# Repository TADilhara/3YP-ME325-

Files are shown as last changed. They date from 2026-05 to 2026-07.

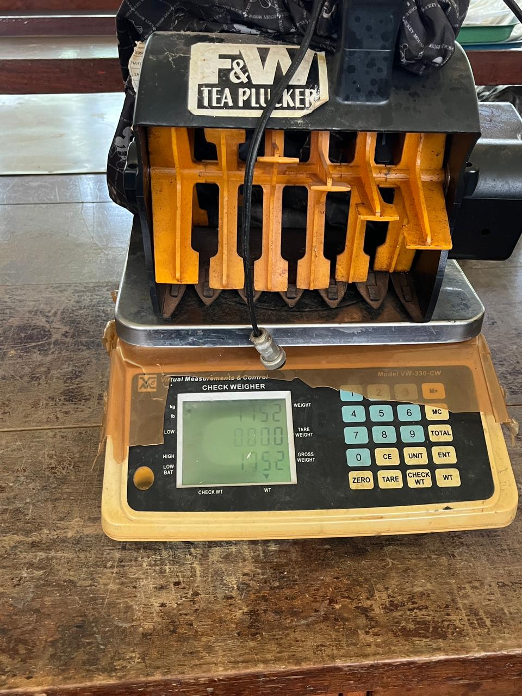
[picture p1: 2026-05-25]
Field_Observations_01/Images/IMG_9.jpeg

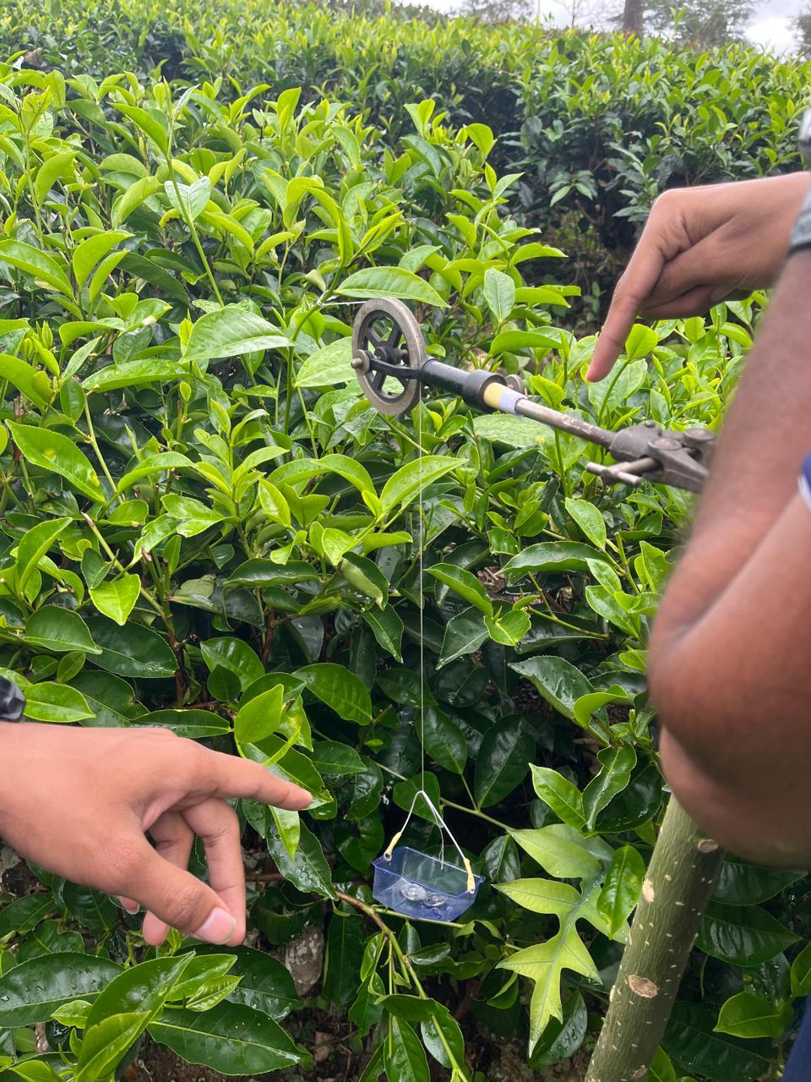
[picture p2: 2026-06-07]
Field_Observations_02/Images/IMG_8.jpeg

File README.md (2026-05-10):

Improved Tea Harvesting Machine Project

Project Overview
This repository contains the documentation, research, and design files for our 3rd-year Mechanical Engineering project. Our objective is to modify and improve existing tea plucking machinery to enable the collection of premium tea products.

Team Members
* Theekshana Dilhara (E/21/097)
* Yugan Shachithra (E/21/099)
* Keshani Kawshalya (E/21/218)

Instructors & Supervisors:
* Course Coordinator: Dr. Sanjeeva Maithripala
* Supervisor: Dr. Elan Sivakumar

Project Log & Milestones

1. Field Research & Site Visits
* Conducted a site visit to the Tea Research Institute Low country Regional Centre,Ratnapura.
* Observed current harvesting methods and identified practical field constraints.

2. Literature Review
* Analyzed existing research papers regarding tea harvesting mechanisms.
* Extracted key data to form the theoretical foundation of our modifications.

3. Conceptualization & Supervisor Meetings
* Conducted brainstorming and feedback sessions with our project supervisor.
* Developed initial mechanical concepts and design directions based on our field research and literature review.

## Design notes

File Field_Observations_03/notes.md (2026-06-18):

# Field Visit & Prototyping Notes: Meewathura Field Premises

**Date:** 10/06/2026  
**Purpose:** Field testing of the physical prototype for 'Guide A'.  
**Attendees:** 
* E/21/097 Dilhara
* E/21/099 Dilshan
* E/21/218 Kaushalya

**Academic Contacts:**  Prof. A.J. Mohotti (Department of Crop Science, Faculty of Agriculture, University of Peradeniya)

## Technical Prototyping Workflow

### 1. Prototype Fabrication
* **Material Selection:** To allow maximum visual tracking of the tea shoots as they slide through the channel, a 5 mm thick clear **Perspex (Acrylic)** sheet was selected.
* **Manufacturing Process:** Using the precise CAD layout from our design files (`Guide_A.pdf`), a 275 mm long scaled test segment of the guide channel was processed using the CNC laser cutter machine located in the Department of Manufacturing and Industrial Engineering.

### 2. Field Testing Methodology
* **Location:** Field experiments were conducted at the tea plots within the Meewathura premises under the guidance of Prof. A.J. Mohotti.
* **Mechanism Simulation:** To validate the tooth spacing, channel width, and sequence of the dual-sorting concept without building full spring sub-assemblies, the physical Perspex guide was passed over living bushes. Human fingers were utilized to manually simulate the mechanical resistive forces of the 1st and 2nd gates.

---

## Key Technical Observations & Encountered Challenges

The initial test confirmed that the basic sliding clearance and physical pathing of the guide work well. However, three critical behavioral problems were isolated during shoot interaction:

### 1. Second Gate Angular Misalignment (Harvestable Shoot Escape)
* **Observation:** The 1st gate successfully filters out the flexible *Arimbu* shoots. This leaves a dense mixture of optimal harvestable shoots and stiff over-mature stalks entering the zone of the 2nd gate.
* **The Problem:** Because the 2nd gate's angular geometry was identical to the first, optimal harvestable shoots were frequently forced to bend too heavily and slip right past the 2nd gate instead of triggering it. As a result, these high-quality leaves bypassed the cutting plane entirely and were left unharvested.

### 2. Shoot Clustering (Bunch of Tea Shoots Phenomenon)
* **Observation:** Tea shoots do not always enter the guide teeth as isolated, individual stalks; they frequently enter as a tightly packed **bunch of tea shoots**.
* **The Problem:** When a dense bunch of tea shoots strikes the gates, the combined collective force of multiple harvestable/mature shoots easily overpowers the gate pre-load simultaneously. This causes the gates to blow wide open, destroying the sorting selectivity and allowing *Arimbu* within the bunch to be cut, or mature wood to pass.

### 3. Forward Leaning Stalks & Collection Loss (Falling Defect)
* **Observation:** As shoots approach the final cutting plane near the reciprocating blades, they exhibit a distinct forward leaning profile (bending toward the front of the machine).
* **The Problem:** Immediately after the cutter bar shears the stem, the forward momentum and preset lean cause the severed shoot to flip and **fall down forward** onto the field floor instead of being swept backward into the collection bag. This introduces an unacceptable crop collection loss.

---

## Iterative Design Modifications & Solutions

To resolve these three field-identified bottlenecks, our group is shifting from a single geometry to an comparative array testing workflow:

* **Development of Guides B and C:** We are designing two additional guide variants with localized, targeted geometric adjustments:
  * **Optimized 2nd Gate Trajectory:** Altering the entry angle and length of the second channel slot to reduce the deflection requirements for harvestable leaves, ensuring they are consistently guided directly to the blade.
  * **Anti-Tumble Extension Profiles:** Modifying the front lip of the teeth to brace leaning stalks upright right up to the millisecond of the cut, preventing the forward falling defect.
  * **Cluster-Breaking Tooth Profiling:** Introducing subtle modifications to the entry nose of the teeth to mechanically break apart "Pokura" clusters into individual lines before they strike the first gate pocket.

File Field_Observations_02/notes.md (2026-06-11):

# Field Visit Notes: 	Tea Research Institute of Sri Lanka, Talawakelle

**Date:** 22/05/2026  
**Purpose:** Primary mechanical property data collection and structural analysis – measure shoot bending forces, evaluate stem diameter profiles.  
**Attendees:** 

* E/21/097 Dilhara
* E/21/099 Dilshan
* E/21/218 Kaushalya
* Dr. Elan Sivakumar (Project Supervisor / Department of Mechanical Engineering, University of Peradeniya)

## Key Observations & Data Collection

### 1. Custom Bending Force Apparatus
To determine the stiffness boundary conditions for our selective mechanism design, our team deployed a custom mechanical testing apparatus directly in the field patches.
* **Component Assembly:** The system utilizes a rigid structural clamp to secure the base of the living tea stem without crushing the plant tissue. A low-friction pulley wheel with an integrated holder is aligned horizontally with the target pluck point via a high-tensile thread link. The thread terminates at a calibrated scale pan used to apply incremental vertical loads.
* **Testing Methodology:** Force application is managed using calibrated laboratory weights supplemented by a precise combination of Sri Lankan currency coins (with known masses verified in our coin-weight lookup tables) to achieve fractional gram sensitivities. Weights are added slowly until the stalk reaches its critical large-deflection bending threshold, allowing us to back-calculate the mechanical yield limits in Newtons ($F = m \cdot g$).

### 2. Shoot Bending Force & Stem Diameter Metrics
Using our custom testing apparatus and precision vernier calipers, we successfully isolated the distinct mechanical properties separating immature, harvestable, and over-mature stalks:
* **Arimbu (Immature Stems):** Displayed a highly flexible biological nature with a narrow stem diameter. The maximum force threshold required to bend an *Arimbu* shoot tip safely sat at **0.1089 N**, setting our mechanism's absolute baseline resistance limit.
* **Harvestable Shoots (Pluckable):** Standard "2-3 leaves and a bud" structures showed a clean nominal diameter profile at their natural breaking points. These shoots displayed a clear force range starting from a minimum of **0.1178 N** up to a maximum peak of **0.3226 N**.
* **Mature Shoots (Coarse Wood Stalks):** Heavily lignified, dense mature stems exhibited significantly larger cross-sectional diameters, requiring extreme forces exceeding **0.50 N - 0.70 N** to achieve deflection, validating our stiffness-sorting criteria.

### 3. Field Agronomy & Structural Observations
* **Manual Harvesting Baseline:** Accompanied by the TRI officers, we monitored plantation pluckers to study the kinematic motion of hand selection. Experienced labor isolates pluckable shoots with high accuracy, leaving delicate *Arimbu* tips pristine for subsequent 7-day or 9-day cycles.
* **Morphological Features:** Detailed structural evaluations confirmed that the mechanical layout must adapt to variable stalk maturity across uneven tea tables, confirming that a geometry-only sorting method is insufficient compared to our stiffness-gate approach.

### 4. Commercial Tea Factory Processing Pipeline
* **Industrial Validation:** Visited the manufacturing plant facilities to analyze how mechanical harvesting affects subsequent processing stages.
* **Coarse Leaf Impact:** Factory operators confirmed that non-selective machine harvesting introduces high percentages of coarse wood stems, which disrupts the automated sifting/withering machines and degrades the overall value grade of the final product.

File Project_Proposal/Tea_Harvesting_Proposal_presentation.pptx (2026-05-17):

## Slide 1

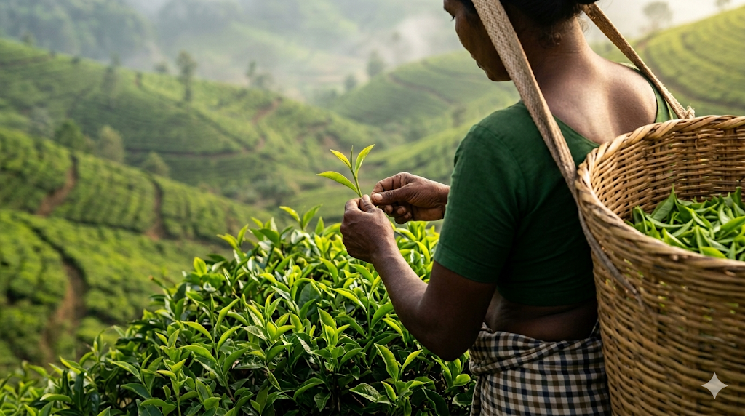
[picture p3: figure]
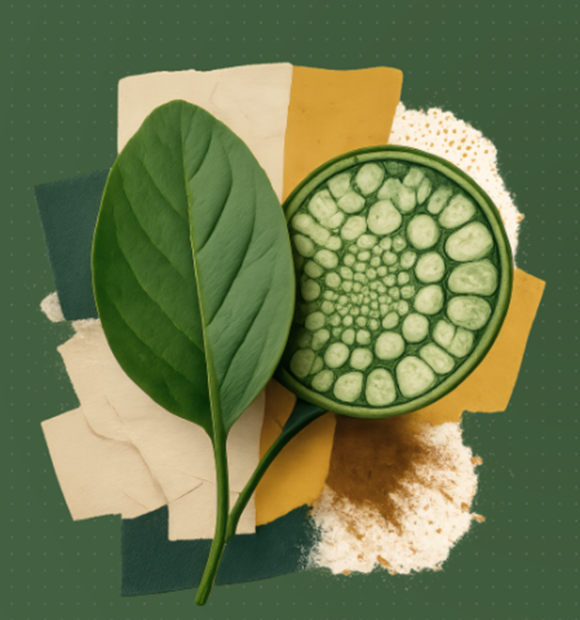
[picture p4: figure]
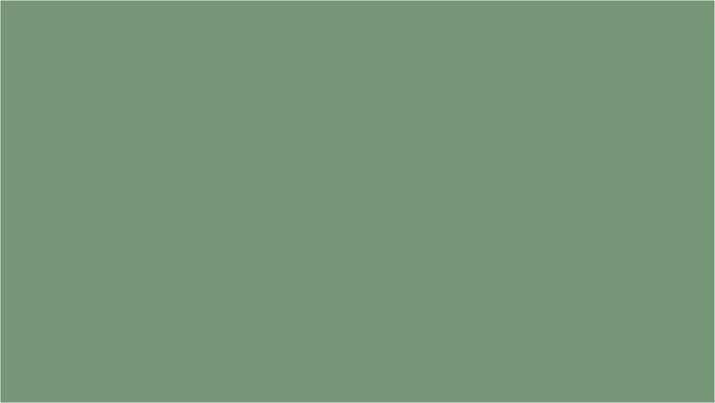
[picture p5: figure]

Adaptive Design for
Precision Tea Harvesting

Evaluation of Existing Systems &
Development of Improvement Recommendations

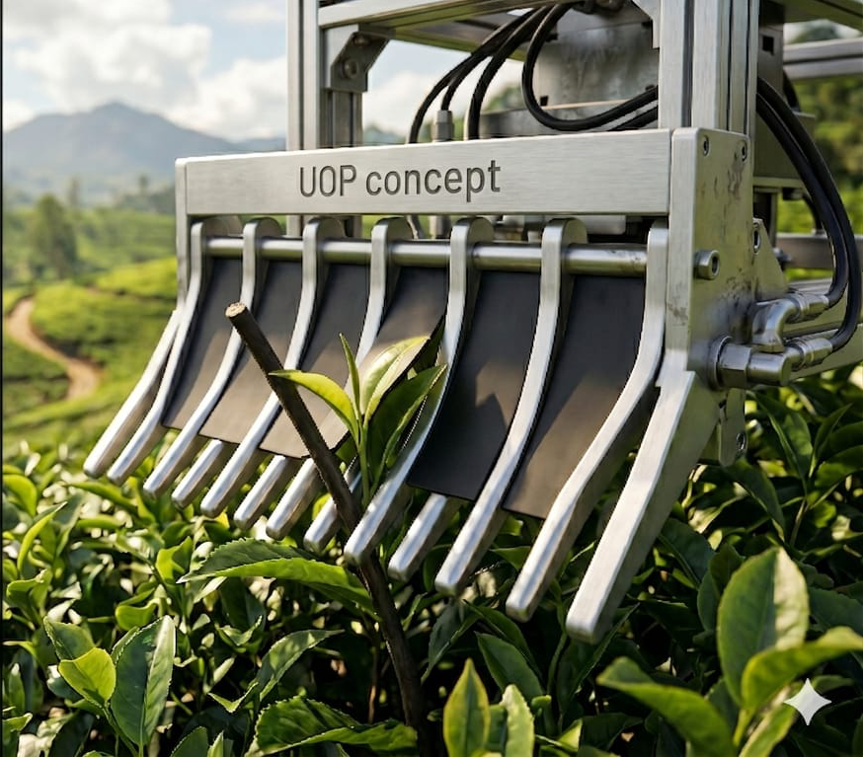
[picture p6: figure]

🍃 Tea Harvesting Research

ME325 — Mechanical Engineering Group Project

Group Members
Theekshana Dilhara [E/21/097]
Yugan Sachithra [E/21/099]
Keshani Kaushalya [E/21/218]

Supervised by
Dr. Elan Sivakumar

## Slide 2

TEA SHOOT BIOLOGY & PLUCKING SCIENCE

- Understanding tea shoot anatomy is essential to designing a selective harvesting mechanism.

01

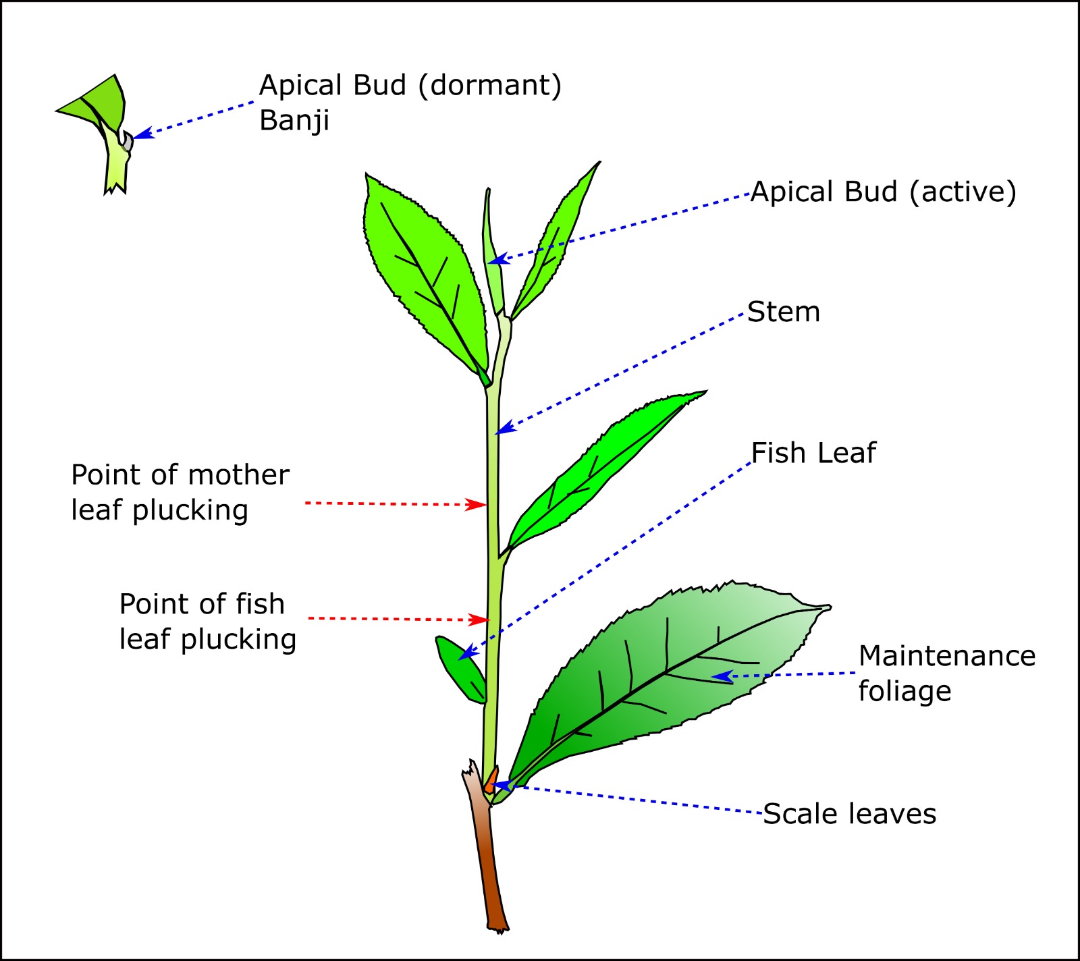
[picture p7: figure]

🌱 Shoot Growth Stages (a → e)

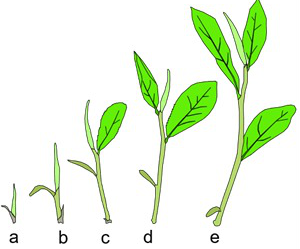
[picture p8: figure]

🍃 Key Plucking Facts

- • Pluckable shoot = Apical Bud + 2–3 tender leaves
- • Arimbu = immature shoot — must NOT be harvested
- • Banji = dormant bud — not ideal for plucking
- • Maintenance foliage must be preserved for photosynthesis
- • Fish leaf marks the lower boundary of plucking zone

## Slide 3

THE PROBLEM & AIM

02

📌 PROBLEM: Labour shortages and rising costs are forcing tea estates to adopt mechanical harvesting — but current machines damage leaves, lack selectivity, and fail on steep Sri Lankan terrain.

❌ WHY CURRENT MACHINES FAIL

- Machines cannot detect precise plucking level
- Cannot distinguish Arimbu / banji shoots
- 35–40% yield loss; heavy leaf damage

✅ PROPOSED APPROACH

Selective harvesting — targets only pluckable shoots
Evaluates stem rigidity, bending angles & node count
Computer vision and sensors to detect buds in real time
Adaptable cutting height for uneven terrain
Reduced leaf damage & improved tea quality
Data-driven design validated through FEA & simulation

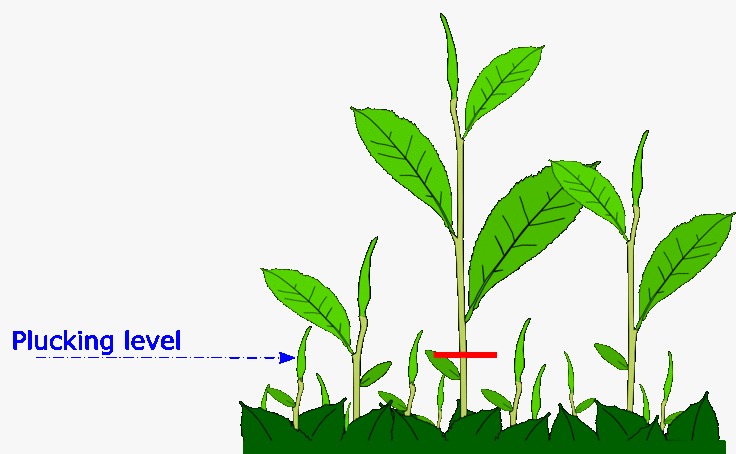
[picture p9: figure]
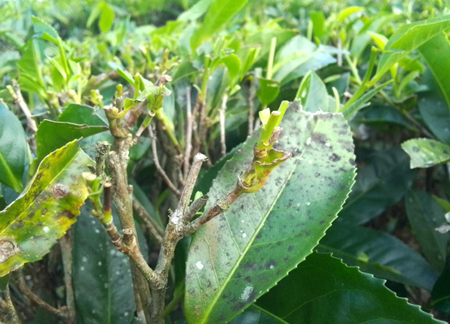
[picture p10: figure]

VS

🎯 AIM: Conduct a systematic comparative analysis of tea plucking harvesters and propose practical design improvements for Sri Lankan plantation conditions.

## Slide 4

COMPARATIVE ANALYSIS OF TEA PLUCKING MACHINES

03

- Field study informed by Tea Research Institute of Sri Lanka (TRI), Rathnapura

Criterion | Kawasaki Petrol Operated Harvester | Kawasaki Impeller | Battery Harvester | TRI Shear Plucker | Static Teeth
Power Source | Petrol | Battery ✅ | Battery ✅ | Human | Battery ✅
Daily Output | 0.7–1.0 ac/day (15× faster) | < NV60H (10× faster) | 30+ kg/hr (similar speed) | 4.3 kg/hr (2× faster) | Very low
Leaf Quality | Poor — many broken leaves | Poor — fans bruise leaves | Moderate < 10% coarse | Good — close to manual | Very poor — teeth jam
Selectivity | None | None | Low | Partial | None
Sri Lanka Terrain | Hilly (partly) | Hilly (partly) | Any land | Any land | Not tested
SL Pluck Cycle | 14–16 days ✅ | 14–16 days ✅ | 14–16 days ✅ | 7 days ✅ | Not suitable
Overall Rating | 🟢🟢🟢⚪⚪ 3 / 5 | 🟡🟡⚪⚪⚪ 2 / 5 | 🟢🟢🟢⚪⚪ 3 / 5 | 🟢🟢🟢🟢⚪ 4 / 5 | 🔴⚪⚪⚪⚪ 1 / 5

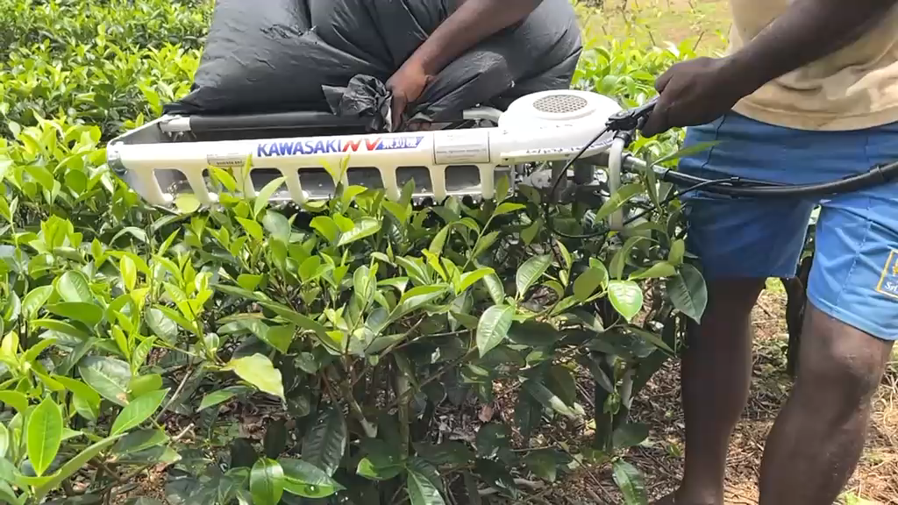
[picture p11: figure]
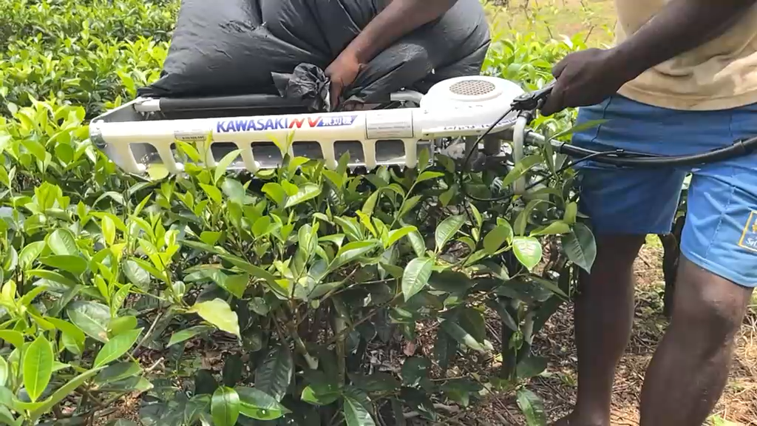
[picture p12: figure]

Operation of the currently using machine

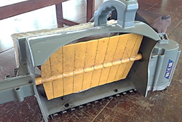
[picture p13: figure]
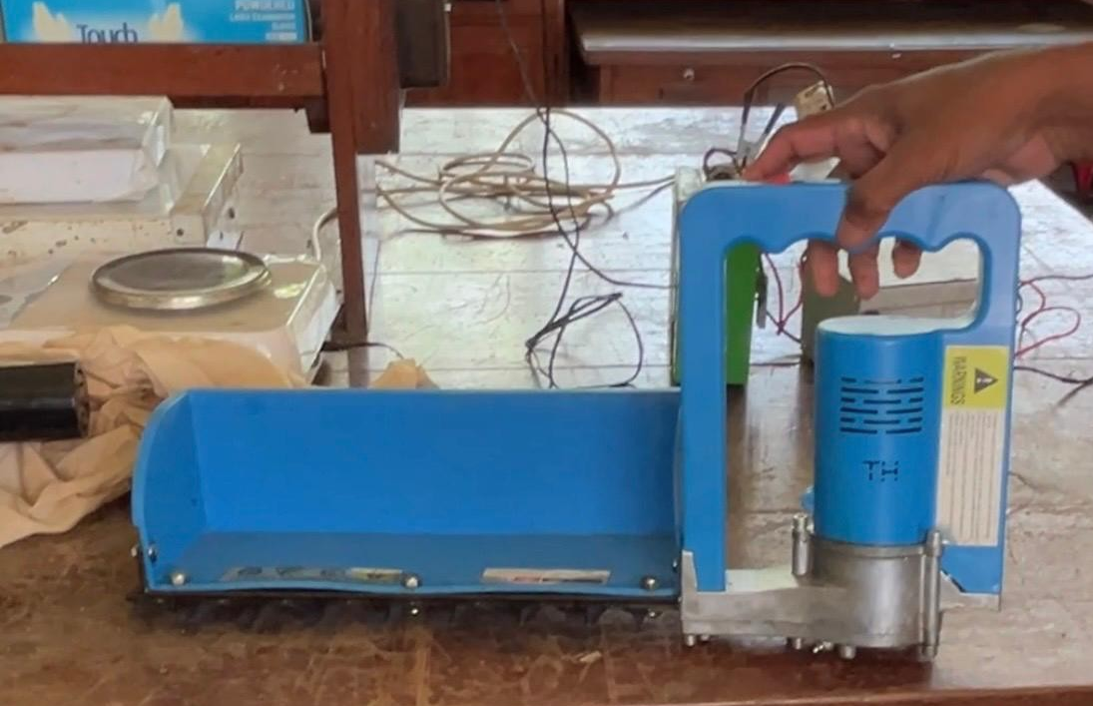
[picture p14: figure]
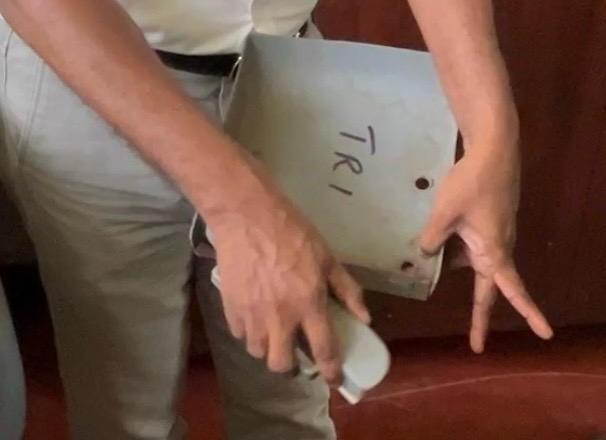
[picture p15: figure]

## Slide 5

📡 Concept A: Sensor-Guided Bending Shear

ENGINEERING DESIGN & METHODOLOGY

🤖 Concept C: Stiffness Based Selection Gate

A mechanical comb attachment uses flexible strips to sort shoots by stem stiffness. Flexible immature shoots bend safely underneath the gates, while rigid mature stems push the gates open to reach the cutting blades.

04

🔬 Concept B: Optical Micro-Shear System

Front facing camera scans canopy, identifies the topmost bud, and counts leaf nodes. If node count ≥ 3, a localized micro-shear severs the specific stem without collateral damage.

Exploits stem flexural rigidity. Deflector bends mature stems to 80° yield point. Sensor array detects bud position → dynamically adjustable blade targets the exact internode.

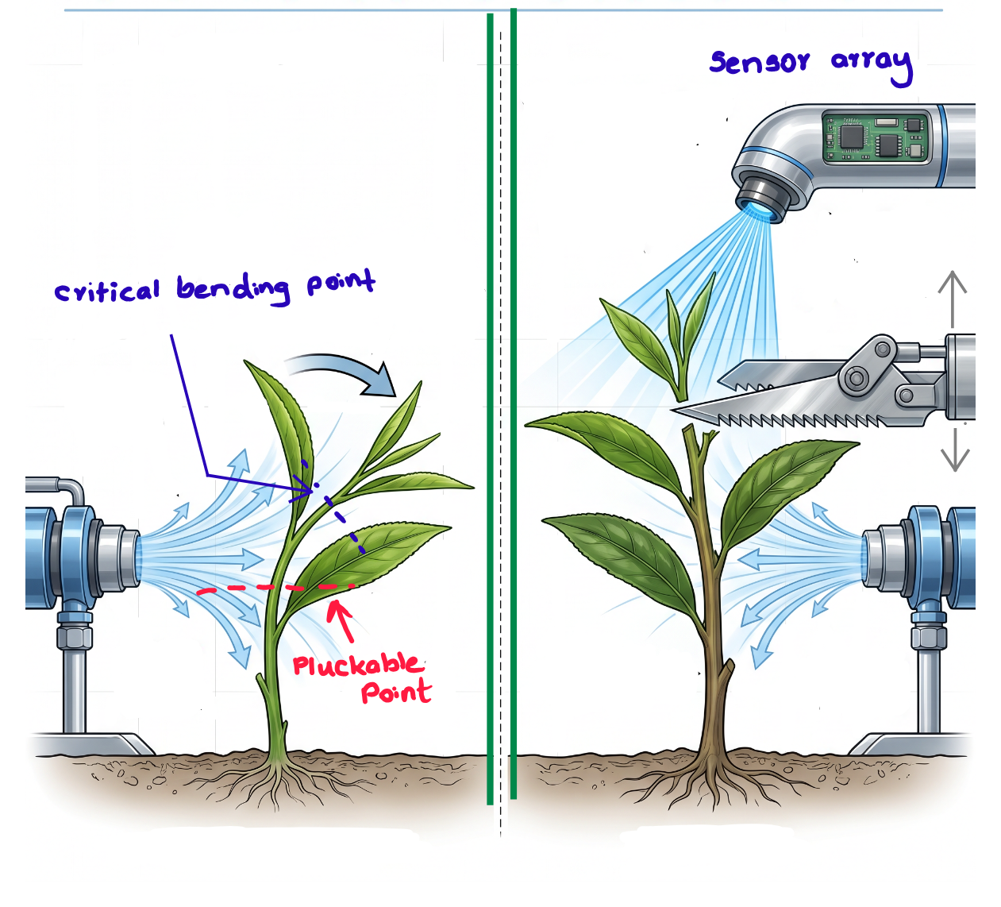
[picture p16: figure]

SOFTWARE TOOLS:

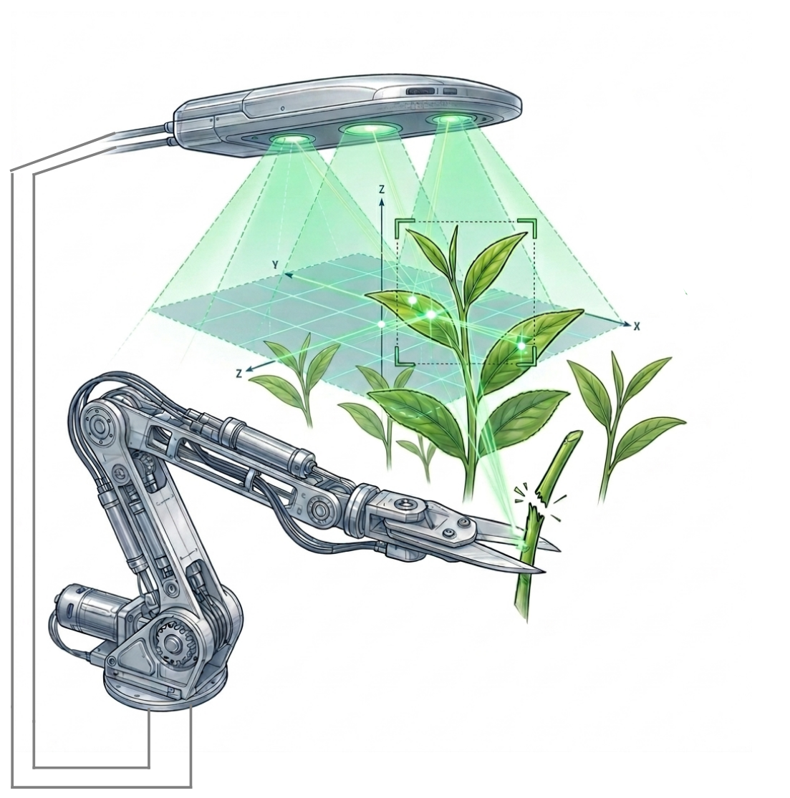
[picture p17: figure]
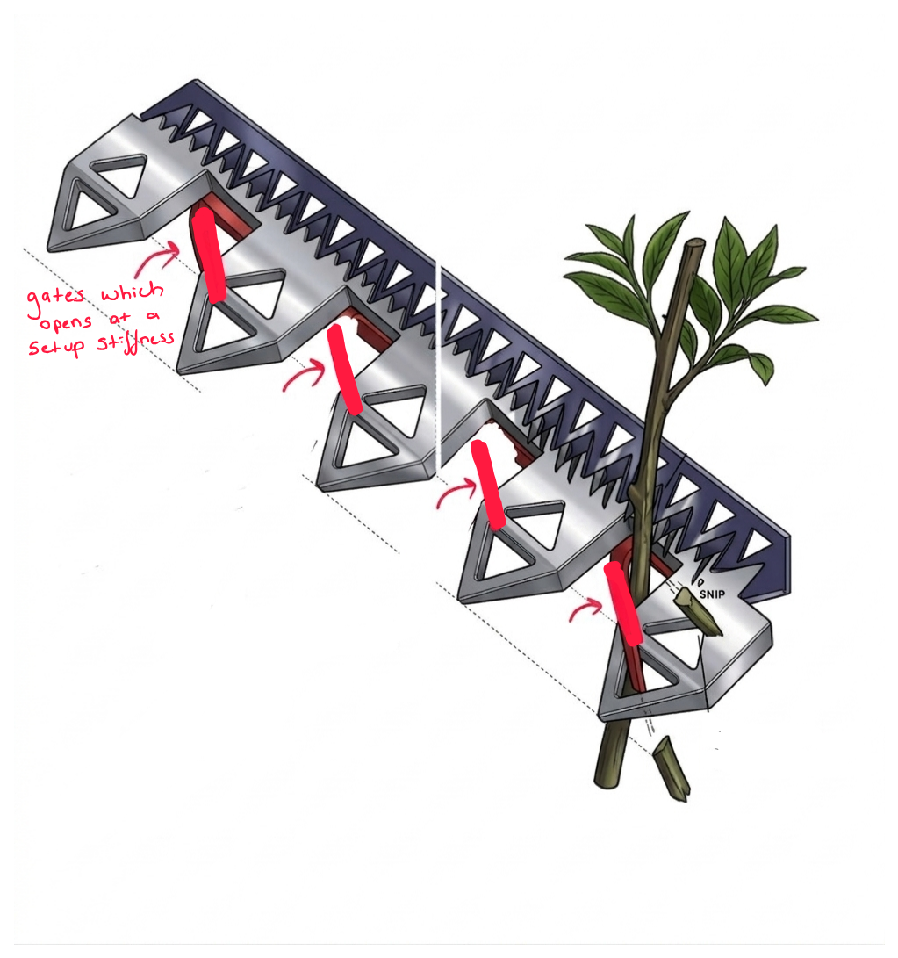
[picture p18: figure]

SolidWorks 2024 · Ansys FEA · MATLAB / Python · GitHub

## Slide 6

PROJECT TIMELINE — 4 MILESTONES

05

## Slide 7

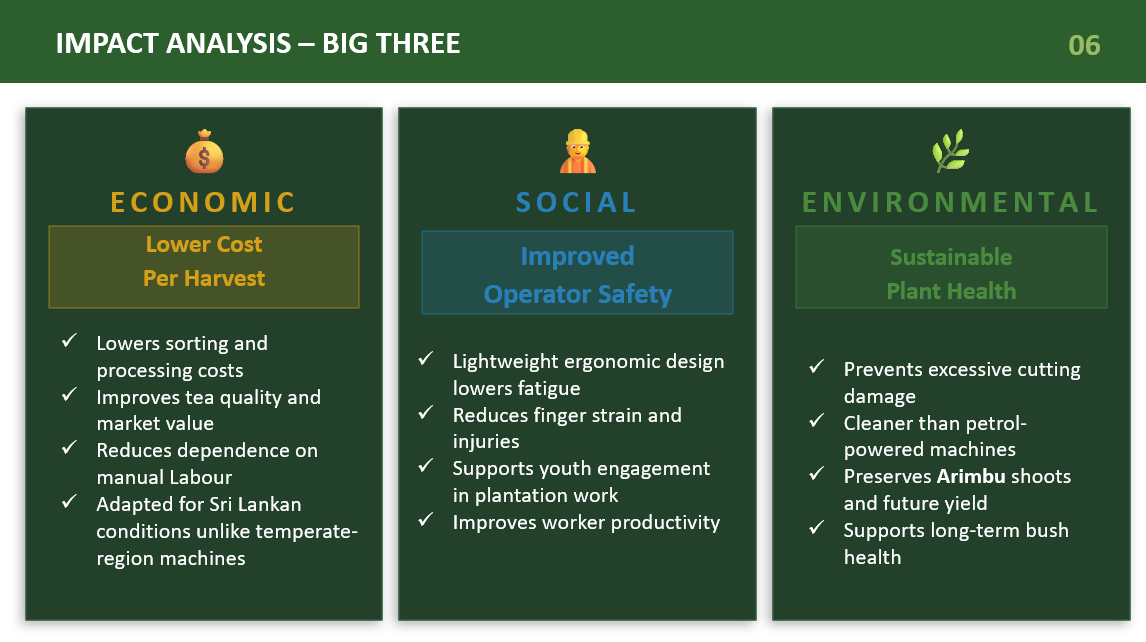
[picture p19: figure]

Ready for the Next Generation of Tea Harvesters?
Let’s innovate, Efficient & Quality-Oriented Solutions

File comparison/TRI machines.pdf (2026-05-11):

Machine | Power Source | Weight/ kg | Cutting Mechanism | Output / Efficiency | Figures

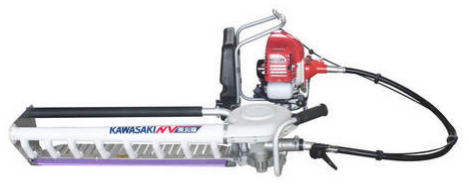
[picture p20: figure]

Kawasaki NV60H | Petrol (TU26 Mitsubishi engine, 2 Stroke, Air cool) | 9.4 (Engine 6.2kg) | Shear blades (Blade length 600mm) | 0.7–1.0 acre/day, ~15× faster than manual plucking

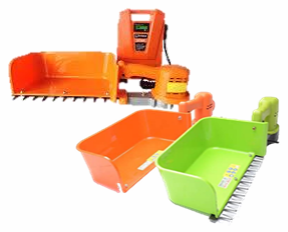
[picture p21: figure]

Single Hand Electric Tea Harveste r | Battery powered | 1.8 | Shear blades (Blade length 330mm) | 30+ kg/hr (similar speed)

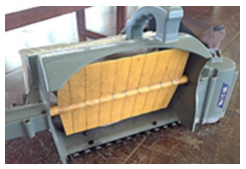
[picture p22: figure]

Kawasaki Impeller machine | Battery powered | 3.5 | Shear blades with impeller/fan | Faster than manual, lower than NV60H

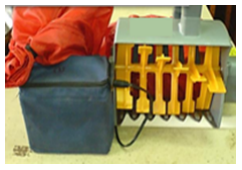
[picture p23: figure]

Static Teeth Machine | Battery powered | 1.75 | Fixed teeth cutting system | Very low efficiency

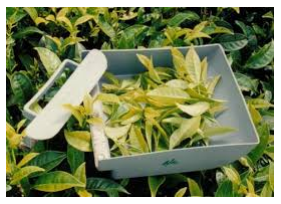
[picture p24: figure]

TRI selective harvestin g shear | Manual | <1 | Scissor mechanism | 4.3 kg/hour, ~2× faster than hand plucking

05

## 2. Analysis of Existing Systems 2.1 Technical Specifications of Existing Tea Harvesting Machines

Table 01: Technical Specifications of Common Tea Harvesting Machines Used in Sri Lanka and

### Similar Plantation Systems

Machine | Tea Quality Performance | Major Specifications | Main Limitations
Kawasaki NV60H | Low quality due to broken leaves, coarse leaves, and stem inclusion | High cutting speed, widely used | No selective plucking → harvests bud + coarse leaves together; high leaf damage; operator fatigue; post-sorting required
Single Hand Electric Tea Harvester | Moderate quality (non-selective) | Lightweight, portable | No bud-selectivity → mixed leaf harvest; battery dependency; limited coverage width; operator wrist fatigue during long use
Kawasaki Impeller machine | Moderate–low quality | Lightweight, improved handling | Leaf bruising due to impeller action; poor selectivity
Static Teeth Machine | Very poor quality | Simple mechanical design | Jamming in dense tea bushes; uneven cutting; high coarse leaf content; unsuitable for Sri Lanka terrain
TRI selective harvestin g shear | High quality (closest to hand plucking) | Simple, low cost | Low productivity; fatigue; not suitable for steep slopes

06

### Table 02: Performance Evaluation of Tea Harvesting Machines Based on Tea Quality and Operational Limitations

## 2.2 Performance Comparison of Tea Harvesting Machines

Machine | Harvesting Efficiency | Tea Quality | Selectivity | Ergonomics (Operator Comfort) | Overall Rating (Average)
Kawasaki NV60H | 5 | 2 | 1 | 1 | 2.25
Single Hand Electric Harvester | 4 | 2 | 1 | 3 | 2.5
Kawasaki Impeller Machine | 3 | 3 | 2 | 4 | 3
Static Teeth Machine | 3 | 3 | 2 | 3 | 2.75
TRI selective harvesting shear | 2 | 5 | 4 | 4 | 3.75

## 2.3 Comparative Rating of Tea Harvesting Machines

### Table 03: Comparative Performance Rating of Tea Harvesting Machines Based on Key Evaluation Criteria

### Scale 5 = Excellent 4 = Good 3 = Moderate 2 = Poor 1 = Very Poor

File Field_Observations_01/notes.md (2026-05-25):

# Field Visit Notes: TRI Sub Centre, Ratnapura

**Date:** 04/05/2026  
**Purpose:** Primary data collection for project – observe manual vs. mechanical tea harvesting, identify limitations of existing systems and understand tea shoot morphology.  
**Attendees:** 
* E/21/097 Dilhara
* E/21/099 Dilshan
* E/21/218 Kaushalya

**TRI Contact:** Dr. S.R.W. Pathiranage (Head of low country regional centre / Senior research officer)

## Key Observations

### 1. Manual Plucking
* **High Selectivity:** Workers consistently pick "2–3 leaves and a bud".
* **Arimbu Conservation:** *Arimbu* (immature shoots) are left intentionally for the next plucking round (7 days).
* **Labor Output:** Skilled pluckers achieve 15–20 kg/day, but labor shortages are highly visible.

### 2. Mechanical Harvesters (Kawasaki NV60H)
* **Non-Selective Cutting:** Removes buds, coarse leaves, stems, and *Arimbu* all together.
* **Yield Loss:** Estimated 35–40% yield loss due to the accidental removal of immature shoots.
* **Biological Damage:** Damage to maintenance foliage (mother leaves) severely affects future photosynthesis.
* **Terrain Constraints:** On steep slopes, operators struggle to maintain a constant, stable cutting height.

### 3. Tea Shoot Structure
* **Morphology:** Apical bud, fish leaf, and mother leaf were clearly identified during the field observation with the TRI officer.
* **Banji Shoots:** *Banji* shoots (dormant buds) are present in dry patches, which current non-selective machines cannot detect.
* **Plucking Table:** The plucking table height is highly uneven due to the rugged terrain, causing over-cutting or completely missed shoots.

### 4. TRI Selective Harvesting Shear
* **Quality & Speed:** Provides much better quality (2× faster than hand plucking with good selectivity).
* **Limitations:** Displays low overall productivity (4.3 kg/hr) and causes severe hand fatigue on slopes. It is currently not suitable for large-scale application.

## Media Logs

### Photos
* **IMG_1:** Our team with Dr. S.R.W. Pathiranage.
* **IMG_2:** Harvestable shoot.
* **IMG_3:** Tea bush after plucking.
* **IMG_4:** Kawasaki NV60H machine.
* **IMG_5:** Cutting blades in Kawasaki NV60H machine.
* **IMG_6:** Impeller machine.
* **IMG_7:** Cutting blades in impeller machine.
* **IMG_9:** Static teeth machine.

### Videos
* **VID_1:** Tea Shoot Morphology Explanation.
* **VID_2:** Kawasaki NV60H machine.
* **VID_3:** Old shears & TRI shear.
* **VID_4:** TRI shear.
* **VID_5:** Impeller machine.
* **VID_6:** Static teeth machine.
* **VID_7:** Single hand electric tea harvester.
* **VID_8:** Another machine.
* **VID_9:** Operation of Kawasaki NV60H Machine.

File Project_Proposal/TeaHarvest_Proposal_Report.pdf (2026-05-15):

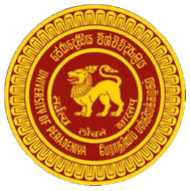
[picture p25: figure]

## Comparative Analysis of Tea Plucking Harvesters: Evaluation of Existing Systems and Development of Improvement Recommendations

ME325- Mechanical Engineering Group Project

Department of Mechanical Engineering Faculty of Engineering
University of Peradeniya

By
E/21/097 Dilhara I.W.A.T.A. E/21/099 Dilshan J.P.Y.S.
E/21/218 Kaushalya K.G.K.

Supervise By
Dr. Elan Sivakumar

Content....

1.Introduction
a.Background
b.Purpose and Need of the Project
2.Analysis of Existing Systems
a.Technical Specifications of Existing Tea Harvesting Machines b.Performance Comparison of Tea Harvesting Machines c.Comparative Rating of Tea Harvesting Machines
3.Project Objectives & Methodology
a.Project Objectives
b.Project Methodology
4.Project Planning & Timeline 5.Impact Analysis
a.Economic Considerations
b.Social Considerations
c.Environmental Considerations 6.References

### 1. Introduction 1.1 Background

Tea is a major agricultural crop in Sri Lanka and makes an important contribution to the national economy through export income, employment, and rural development. Sri Lanka is well known worldwide for producing high-quality Ceylon tea.Tea harvesting is one of the most labour-intensive tasks in tea production, as plucking must be carried out regularly while maintaining strict quality standards. Traditionally, tea leaves are harvested manually by skilled workers who carefully select tender shoots to ensure better quality and future plant growth. However, the tea industry is currently facing major challenges such as labour shortages, increasing wages, and high production costs, making manual plucking less sustainable. To address these issues, mechanical tea harvesting systems such as handheld shears, motorized harvesters, and portable tea plucking machines have been introduced to improve efficiency and reduce dependence on labour. Although these technologies can increase harvesting speed, they also create problems including leaf damage, poor shoot selection, inclusion of coarse material, and operational difficulties in uneven field conditions.
A major challenge in mechanical tea harvesting is maintaining the required plucking standard. In tea cultivation, the harvestable portion is called the pluckable shoot, which generally consists of a bud with two or three tender leaves. The plucking standard varies depending on climatic conditions and plantation management practices. During wet seasons, rapid plant growth allows comparatively harder plucking standards such as three leaves and a bud, while during dry seasons lighter plucking standards such as two leaves and a bud are preferred to maintain tea quality.
Understanding tea shoot structure is essential when analyzing mechanical tea harvesting systems because harvesting efficiency and quality depend on correctly identifying pluckable shoots. A tea shoot consists of the apical bud, which is the actively growing terminal bud responsible for shoot elongation, followed by progressively developing young leaves. Near the shoot base, the first immature protective leaf is called the fish leaf, while the mature supporting leaf left after harvesting is known as the mother leaf. Very young immature shoots not ready for harvesting are locally called Arimbu and must remain until reaching the required plucking stage. Tea buds can be classified as active buds and dormant buds, depending on growth conditions, while some shoots may enter a temporary resting condition called banji, where the apical bud becomes inactive and shoot growth stops, making them unsuitable as ideal pluckable shoots. After harvesting, new shoots regenerate from remaining buds, with growth influenced by temperature, rainfall, sunlight, and soil moisture. Tea bushes are maintained at a uniform height known as the plucking table, and the time interval between two harvesting cycles is called the plucking round, both of which are important for maintaining sustainable yield and tea quality.

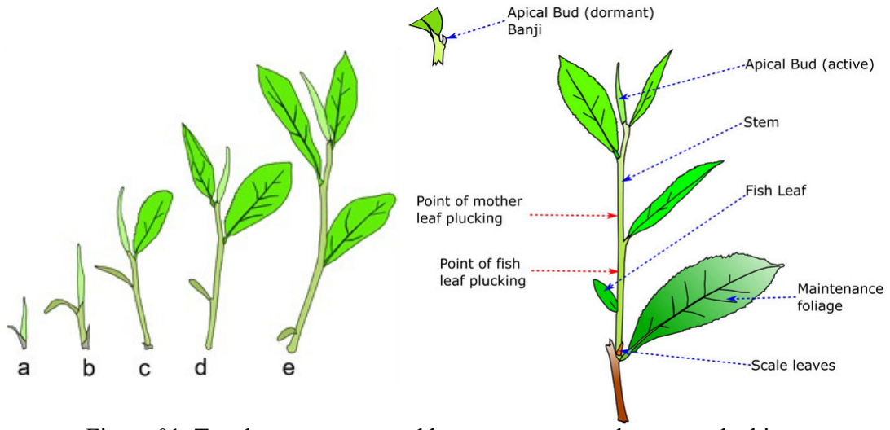
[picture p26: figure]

Figure 01: Tea shoot structure and key components relevant to plucking.

Tea-growing regions can generally be divided into tropical regions and temperate regions according to climatic conditions. Sri Lanka belongs to the tropical region, where relatively warm temperatures and seasonal rainfall allow tea plants to grow continuously throughout most of the year. Because of this continuous growth, tea bushes in Sri Lanka require frequent plucking rounds, often within 7–14 days depending on weather conditions and elevation. In contrast, tea-growing countries in temperate regions experience colder seasons and slower plant growth, resulting in longer plucking intervals and seasonal harvesting patterns.
Climatic and field condition differences create major challenges when applying tea harvesting machines developed for temperate regions to Sri Lankan plantations. These machines are generally designed for uniform terrain, slower shoot growth, and longer plucking rounds, whereas Sri Lankan tea fields have steep slopes, uneven terrain, dense shoot growth, and shorter plucking cycles. As a result, many imported machines show poor adaptability and cannot maintain accurate selective plucking standards. A major limitation is the inability to distinguish between pluckable shoots and non-pluckable shoots such as Arimbu, banji shoots, and other immature developing shoots, causing machines to harvest both required and non-required material simultaneously. This reduces tea quality, damages future yield potential, increases the inclusion of coarse leaves and stems, and, due to uneven terrain, makes it difficult to maintain a constant cutting height, resulting in inconsistent harvesting performance and increased operator fatigue.

### 1.2 Purpose and Need of the Project

Mechanical tea harvesting systems have been introduced as a possible solution to reduce labour dependency and increase harvesting productivity. Although these systems improve harvesting speed, many existing machines are unable to satisfy the quality requirements.. The major technical issue is the lack of selective plucking capability. Existing machines cannot properly differentiate between mature pluckable shoots and immature shoots such as Arimbu, active buds, and developing shoots intended for future plucking rounds. Consequently, machines remove both required and non-required shoots together, reducing final tea quality and affecting future yield.


Figure 02: Tea Bush Surface after Mechanical Harvesting Showing Non-Selective Cutting Pattern


Figure 03: Field Observation at TRI Showing Tea Bush Damage and Immature Shoot Loss Caused by Existing Mechanical Harvesting Systems

Another major problem is the difficulty of operating mechanical harvesters on uneven terrain. Tea plantations in Sri Lanka are commonly located on steep hillsides and irregular land surfaces. Many available machines are designed for relatively flat tea fields found in temperate regions and therefore cannot maintain a stable cutting height under local plantation conditions. This results in inconsistent plucking, increased leaf damage, operator discomfort, and lower harvesting accuracy.
In addition, differences between tropical and temperate tea-growing conditions significantly affect machine performance. Due to faster shoot growth in tropical climates, Sri Lankan tea bushes require shorter plucking rounds and more accurate harvesting control. Machines developed for temperate regions may not satisfy these requirements because they are designed for different shoot densities, growth patterns, and harvesting intervals.
Therefore, this project is necessary to conduct a detailed evaluation of currently available tea harvesting systems and identify their limitations under Sri Lankan plantation conditions. The findings of this study can contribute toward the development of more suitable harvesting solutions capable of improving harvesting efficiency while maintaining tea quality standards. The project will also provide engineering recommendations for future design improvements focusing on selective plucking capability, terrain adaptability, ergonomic operation, and reduced leaf damage.

### 2. Analysis of Existing Systems

Our team conducted a field visit to the Tea Research Institute (TRI) sub-center in Ratnapura to gather primary data and observe operational benchmarks. During this visit, we conducted a comparative observation of traditional manual plucking and current mechanical systems, specifically focusing on how manual labor achieves high selectivity by identifying mature "two leaves and a bud" shoots while preserving immature Arimbu shoots for future cycles. We analyzed the critical structure of the tea shoot—including the apical bud, fish leaf, and mother leaf—to understand why current machines often fail to distinguish these components, leading to a significant 35–40% yield loss and damage to maintenance foliage. These field insights provided the technical foundation for identifying the performance gaps in existing harvesters and establishing the criteria for our proposed precision harvesting improvements

Machine | Power Source | Weight/ kg | Cutting Mechanism | Output / Efficiency | Figures


Kawasaki NV60H | Petrol (TU26 Mitsubishi engine, 2 Stroke, Air cool) | 9.4 (Engine 6.2kg) | Shear blades (Blade length 600mm) | 0.7–1.0 acre/day, ~15× faster than manual plucking


Single Hand Electric Tea Harveste r | Battery powered | 1.8 | Shear blades (Blade length 330mm) | 30+ kg/hr (similar speed)


Kawasaki Impeller machine | Battery powered | 3.5 | Shear blades with impeller/fan | Faster than manual, lower than NV60H


Static Teeth Machine | Battery powered | 1.75 | Fixed teeth cutting system | Very low efficiency


TRI selective harvestin g shear | Manual | <1 | Scissor mechanism | 4.3 kg/hour, ~2× faster than hand plucking

### 2.1 Technical Specifications of Existing Tea Harvesting Machines

Table 01: Technical Specifications of Common Tea Harvesting Machines Used in Sri Lanka and Similar Plantation Systems

Machine | Tea Quality Performance | Major Specifications | Main Limitations
Kawasaki NV60H | Low quality due to broken leaves, coarse leaves, and stem inclusion | High cutting speed, widely used | No selective plucking → harvests bud + coarse leaves together; high leaf damage; operator fatigue; post-sorting required
Single Hand Electric Tea Harvester | Moderate quality (non-selective) | Lightweight, portable | No bud-selectivity → mixed leaf harvest; battery dependency; limited coverage width; operator wrist fatigue during long use
Kawasaki Impeller machine | Moderate–low quality | Lightweight, improved handling | Leaf bruising due to impeller action; poor selectivity
Static Teeth Machine | Very poor quality | Simple mechanical design | Jamming in dense tea bushes; uneven cutting; high coarse leaf content; unsuitable for Sri Lanka terrain
TRI selective harvestin g shear | High quality (closest to hand plucking) | Simple, low cost | Low productivity; fatigue; not suitable for steep slopes

Table 02: Performance Evaluation of Tea Harvesting Machines Based on Tea Quality and Operational Limitations

### 2.2 Performance Comparison of Tea Harvesting Machines

Machine | Harvesting Efficiency | Tea Quality | Selectivity | Ergonomics (Operator Comfort) | Overall Rating (Average)
Kawasaki NV60H | 5 | 2 | 1 | 1 | 2.25
Single Hand Electric Harvester | 4 | 2 | 1 | 3 | 2.5
Kawasaki Impeller Machine | 3 | 3 | 2 | 4 | 3
Static Teeth Machine | 3 | 3 | 2 | 3 | 2.75
TRI selective harvesting shear | 2 | 5 | 4 | 4 | 3.75
| "Excellent" -10x+ faster than manual; industrial-grade speed | "Excellent" Clean cuts; zero bruising; preserves leaf integrity | "Excellent" only mature shoots are harvested | "Excellent" <2kg; low vibration; ergonomic for 4+ hours

### 2.3 Comparative Rating of Tea Harvesting Machines

Table 03: Comparative Performance Rating of Tea Harvesting Machines Based on Key Evaluation Criteria

Scale
5 = Excellent
4 = Good
3 = Moderate
2 = Poor
1 = Very Poor

### 3.Project Objectives & Methodology 3.1 Project Objectives

The main objective of this project is to develop an adaptive precision tea harvesting solution capable of selectively harvesting pluckable tea shoots while minimizing leaf damage and improving operational efficiency under Sri Lankan plantation conditions.
The specific objectives of the project are as follows:
Primary Objective
To design a precision tea harvesting mechanism capable of selectively harvesting tea shoots based on the standard bud + 2 or 3 leaves plucking requirement.
Secondary Objectives
To study and analyze existing mechanical tea harvesting systems currently used in Sri Lanka and identify their operational limitations.
To evaluate the major challenges associated with non-selective harvesting, including leaf damage, coarse leaf inclusion, and poor adaptability to local terrain.
To develop a lightweight (<2kg) and ergonomic harvesting mechanism suitable for steep and uneven tea plantation environments.
To improve harvesting efficiency while maintaining tea quality comparable to manual plucking standards.
To validate the proposed design through computer-aided modeling and engineering simulation.

### 3.2 Project Methodology 3.2.1. Methodology Workflow


Figure 04: Methodology Workflow

Literature Review / Problem Identification
A literature review was conducted to study tea harvesting practices, plucking standards, tea shoot characteristics, and existing mechanical harvesting systems. A field visit to the Tea Research Institute (TRI) Sub Centre, Rathnapura was carried out to observe manual plucking, machine harvesting operations, tea shoot growth stages, and machine-induced damage to tea bushes.
Based on literature findings and field observations, major limitations of existing harvesting systems were identified, including non-selective plucking, damage to immature shoots, poor terrain adaptability, and operator fatigue. These findings were used to establish the main design requirements of the proposed system, including selective harvesting capability, lightweight structure, ergonomic operation, and reduced plant damage.

Requirement Analysis

Based on the identified limitations of existing harvesting systems, the functional and design requirements of the proposed solution were defined. Key requirements include selective harvesting of pluckable shoots, preservation of immature shoots such as Arimbu, lightweight and ergonomic operation, adaptability to uneven terrain, and minimization of leaf and bush damage. These requirements were used as the primary criteria for concept generation and evaluation.

Concept Generation and Development
Three preliminary design concepts were developed to address the identified limitations.

Concept A – Sensor-Guided Bending Shear Mechanism
Uses stem bending behavior and sensor feedback to identify mature pluckable shoots before cutting.


Figure 05: Concept A

Concept B – Optical Micro-Shear System
Uses camera-based detection and leaf node counting to identify pluckable shoots and activate localized cutting.


Figure 06: Concept B

Concept C – Stiffness-Based Selection Gate
Uses mechanical stiffness differences between mature and immature shoots for passive sorting before cutting.


Figure 07: Concept C
Concept Evaluation & Selection
The generated concepts will be evaluated using a decision matrix based on: selectivity performance
simplicity of mechanism
ergonomic suitability
weight
manufacturability
terrain adaptability
reliability
cost feasibility
The most suitable concept, or combination of features from multiple concepts, will be selected for further development.
Material Selection / Engineering Calculations
Preliminary engineering calculations were carried out to estimate key design parameters such as tea shoot dimensions, cutting force requirements, and basic loading conditions. Based on these requirements, suitable materials were selected by considering strength, weight, corrosion resistance, manufacturability, and cost effectiveness to ensure structural reliability and practical field applicability.
3D CAD Modeling / Simulation & Validation
The selected concept will be developed as a detailed 3D model and assembly to verify component arrangement, mechanism functionality, and overall dimensions. Engineering simulations will then be conducted to evaluate structural performance, stress distribution, deformation behavior, and design feasibility under expected operating conditions.

Software | Purpose
SolidWorks | 3D modeling, assembly development, mechanism design
ANSYS | Structural simulation, stress and deformation analysis
MATLAB / Python | Data processing, calculations, analysis
Microsoft Excel | Data analysis, decision matrices, calculations

Comparative Evaluation
The proposed design will be compared with existing tea harvesting systems based on key criteria such as selectivity, harvesting efficiency, tea quality preservation, ergonomic suitability, and terrain adaptability. This evaluation will be used to assess the effectiveness of the proposed improvements and justify the final design recommendation.
Final Design Recommendation
The proposed design will be compared against existing harvesting systems based on: selectivity
tea quality preservation
ergonomics
terrain adaptability
operational feasibility
Final recommendations for adaptive precision harvesting improvements will be presented.

## 3.3. Software Tools

Table 04: Proposed Software Tools and Engineering Applications for Design, Analysis, and Documentation Phases

### 4. Project Planning & Timeline

Table 05: Project Timeline and Work Breakdown Schedule for the Adaptive Tea Harvesting System Development


### 5. Impact Analysis 5.1 Economic Considerations

The Sri Lankan tea industry currently faces a major labour shortage, increasing the need for efficient harvesting alternatives. The proposed precision harvesting system is expected to improve economic performance through targeted mechanization.
Reduced Harvesting Cost: Mechanized harvesting can significantly reduce labour dependency and lower harvesting costs compared to manual plucking(manual harvesting costs approximately Rs. 375 per kg of made tea), improving overall estate profitability. Improved Tea Market Value: Selective harvesting of pluckable shoots is expected to reduce leaf damage, coarse leaf content, and refuse tea percentages, thereby improving final tea quality and market competitiveness.
Lower Post-Harvest Processing Cost: Precise harvesting minimizes the collection of non-pluckable shoots, reducing sorting requirements and processing losses.
Local Adaptability: Existing harvesting machines are mainly designed for temperate tea-growing regions and show poor adaptability to Sri Lankan terrain and plucking standards. The proposed system introduces a solution specifically adapted to local plantation conditions.

### 5.2 Social Considerations

The proposed system also contributes to workforce safety, labour productivity, and modernization of plantation operations.
Improved Occupational Safety: The mechanized system reduces repetitive finger strain, hand injuries, and musculoskeletal fatigue associated with manual plucking.
Reduced Operator Fatigue: Lightweight and ergonomic design considerations aim to reduce physical stress during prolonged harvesting, particularly on steep slopes. Increased Worker Productivity:Mechanized harvesting can improve daily harvesting capacity, potentially increasing worker earnings and operational efficiency.
Technology Adoption and Youth Engagement:The integration of modern harvesting technology may encourage younger generations to participate in plantation-related work.

### 5.3 Environmental Considerations

Environmental sustainability is a critical factor in the design of the proposed harvesting system.
Preservation of Future Yield: Selective harvesting protects immature Arimbu shoots, preserving future shoot development and maintaining yield continuity.
Reduced Plant Damage: Controlled cutting minimizes deep cutting and unnecessary foliage damage, preserving maintenance leaves required for photosynthesis.

Cleaner Energy Utilization: The adoption of battery-powered or energy-efficient mechanisms can reduce fuel consumption and environmental emissions compared to petrol-powered machines.
Long-Term Bush Health: Reduced harvesting damage minimizes plant stress and supports sustainable tea bush productivity over repeated harvesting cycles.

Anon, (n.d.). Tea Research Institute of Sri Lanka. [online] Available at: https://www.tri.lk/.
S. R. W. Pathiranage and T. G. N. Mahinda,

"Introduction, Scientific Facts, and How to Improve: Practical Perspectives on Mechanical Harvesting,

" Tea Research Institute of Sri Lanka, Agronomy Division, Technical Report/Presentation, 2024
C. Dong, W. Wu, C. Han, Z. Zeng, T. Tang, and W. Liu,

"Plucking Point and Posture Determination of Tea Buds Based on Deep Learning,

" Agriculture, vol. 15, no. 2, art. 144, Jan. 2025. [Online]. Available: https://doi.org/10.3390/agriculture15020144
M. A. Wijeratne, H. W. Shyamalie, and H. Kahatapitiya,

"Management Commitment to
Technology Adoption: A Success Story on Innovative Tea Harvesting System,

" Journal of
the National Institute of Plantation Management, vol. 26, no. 2, pp. 27–33, 2012

### 6. References

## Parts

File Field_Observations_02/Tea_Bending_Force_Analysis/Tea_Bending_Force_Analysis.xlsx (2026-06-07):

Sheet: Coin Weights
Coin Weight Setup for TRI Thalawakale Bending Test
Code | Item / Meaning | Weight per item (g) | Unit | Constant | Value
10g | Standard mass | 10.00 | g | g (m/s²) | 9.81
oo1 | copper Rs.1 Coin / mass code oo1 | 3.64 | g | Pan / holder mass (g) | 3.76
o1 | silver old Rs.1 Coin / mass code o1 | 7.18 | g | Set pan mass to 0 if pan was not used
o2 | silver old Rs.2 Coin / mass code o2 | 6.96 | g
n1 | new Rs.1 Coin / mass code n1 | 3.70 | g
n2 | new Rs.2 Coin / mass code n2 | 4.55 | g
n5 | new Rs.5 Coin / mass code n5 | 5.25 | g
Pan | Pan / hanging holder | 3.76 | g
Force Summary by Shoot Stage
Shoot stage | Minimum force (N) | Maximum force (N)
Pluckable | 0.1178 | 0.3227
Matured | 0.2501 | 0.4245
Arimbu | 0.0732 | 0.1089
Banji | 0.1452 | 0.2156
Not plucking / more matured | 0.2417 | 0.7065

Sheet: Measurements
TRI Thalawakale Bending Force Measurements - Pluckable Force Verification
No | Plucking round / bush | Shoot stage | Sample | 10g count | oo1 count | o1 count | o2 count | n1 count | n2 count | n5 count | Original measurement | Total mass incl. pan (g) | Bending force (N)
1 | 9 days plucking bushes | Pluckable | Pluckable 1 | 1 | 1 | 1 | 0 | 1 | 1 | 0 | 10g + oo1 + o1 + n1 + n2 | 32.83 | 0.322
2 | 9 days plucking bushes | Pluckable | Pluckable 2 | 0 | 0 | 0 | 4 | 0 | 0 | 0 | o2 × 4 | 31.60 | 0.310
3 | 9 days plucking bushes | Pluckable | Pluckable 3 | 1 | 0 | 0 | 0 | 1 | 1 | 1 | 10g + n1 + n2 + n5 | 27.26 | 0.267
4 | 7 days plucking (first year) | Pluckable | Pluckable 1 | 0 | 0 | 0 | 0 | 1 | 1 | 0 | n1 + n2 | 12.01 | 0.118
5 | 7 days plucking (first year) | Pluckable | Pluckable 2 | 0 | 0 | 1 | 0 | 1 | 0 | 0 | o1 + n1 | 14.64 | 0.144
6 | 7 days plucking (first year) | Matured | Matured | 1 | 0 | 1 | 0 | 0 | 1 | 0 | o1 + n2 + 10g | 25.49 | 0.250
7 | 7 days plucking (first year) | Arimbu | Arimbu 1 | 0 | 0 | 0 | 0 | 1 | 0 | 0 | n1 | 7.46 | 0.073
8 | 7 days plucking (first year) | Arimbu | Arimbu 2 | 0 | 0 | 0 | 0 | 1 | 0 | 0 | n1 | 7.46 | 0.073
9 | 7 days plucking (first year) | Banji | Banji | 0 | 1 | 0 | 0 | 2 | 0 | 0 | n1 × 2 + oo1 | 14.80 | 0.145
10 | 7 days plucking (first year) | Not plucking / more matured | More matured 1 | 0 | 0 | 0 | 3 | 0 | 0 | 0 | o2 × 3 | 24.64 | 0.242
11 | 7 days plucking (first year) | Not plucking / more matured | More matured 2 | 1 | 0 | 2 | 5 | 0 | 2 | 0 | 10g + o1 × 2 + o2 × 5 + n2 × 2 | 72.02 | 0.707
12 | 9 days plucking bushes | Pluckable | Pluckable 4 | 1 | 0 | 1 | 0 | 2 | 1 | 0 | 10g + o1 + n1 × 2 + n2 | 32.89 | 0.323
13 | 9 days plucking bushes | Pluckable | Pluckable 5 | 0 | 1 | 0 | 2 | 1 | 1 | 0 | oo1 + o2 × 2 + n1 + n2 | 29.57 | 0.290
14 | 9 days plucking bushes | Matured | Matured 2 | 1 | 0 | 1 | 1 | 0 | 2 | 0 | 10g + o1 + o2 + n2 × 2 | 37.00 | 0.363
15 | 9 days plucking bushes | Matured | Matured 3 | 1 | 1 | 2 | 1 | 0 | 1 | 0 | 10g + oo1 + o1 × 2 + o2 + n2 | 43.27 | 0.424
16 | 9 days plucking bushes | Arimbu | Arimbu 3 | 0 | 0 | 0 | 0 | 1 | 0 | 0 | n1 | 7.46 | 0.073
17 | 9 days plucking bushes | Arimbu | Arimbu 4 | 0 | 1 | 0 | 0 | 1 | 0 | 0 | oo1 + n1 | 11.10 | 0.109
18 | 9 days plucking bushes | Banji | Banji 2 | 0 | 1 | 1 | 0 | 2 | 0 | 0 | oo1 + o1 + n1 × 2 | 21.98 | 0.216
19 | 9 days plucking bushes | Not plucking / more matured | More matured 3 | 1 | 0 | 1 | 3 | 0 | 2 | 0 | 10g + o1 + o2 × 3 + n2 × 2 | 50.92 | 0.500
20 | 7 days plucking (first year) | Pluckable | Pluckable 3 | 0 | 1 | 1 | 0 | 1 | 1 | 0 | oo1 + o1 + n1 + n2 | 22.83 | 0.224
21 | 7 days plucking (first year) | Pluckable | Pluckable 4 | 1 | 0 | 0 | 0 | 1 | 1 | 0 | 10g + n1 + n2 | 22.01 | 0.216
22 | 7 days plucking (first year) | Matured | Matured 2 | 1 | 0 | 1 | 0 | 1 | 2 | 0 | 10g + o1 + n1 + n2 × 2 | 33.74 | 0.331
23 | 7 days plucking (first year) | Arimbu | Arimbu 3 | 0 | 0 | 0 | 0 | 1 | 0 | 0 | n1 | 7.46 | 0.073
24 | 7 days plucking (first year) | Banji | Banji 2 | 0 | 0 | 1 | 0 | 2 | 0 | 0 | o1 + n1 × 2 | 18.34 | 0.180
25 | 7 days plucking (first year) | Not plucking / more matured | More matured 3 | 1 | 0 | 2 | 4 | 0 | 2 | 1 | 10g + o1 × 2 + o2 × 4 + n2 × 2 + n5 | 70.31 | 0.690
26 | 7 days plucking (first year) | Pluckable | Pluckable 5 | 0 | 1 | 0 | 0 | 1 | 1 | 0 | oo1 + n1 + n2 | 15.65 | 0.154
27 | 7 days plucking (first year) | Pluckable | Pluckable 6 | 0 | 0 | 1 | 0 | 1 | 1 | 0 | o1 + n1 + n2 | 19.19 | 0.188
28 | 9 days plucking bushes | Pluckable | Pluckable 6 | 1 | 1 | 0 | 0 | 1 | 0 | 0 | 10g + oo1 + n1 | 21.10 | 0.207
29 | 9 days plucking bushes | Pluckable | Pluckable 7 | 1 | 0 | 0 | 0 | 1 | 1 | 0 | 10g + n1 + n2 | 22.01 | 0.216
30 | 9 days plucking bushes | Pluckable | Pluckable 8 | 1 | 1 | 1 | 0 | 1 | 0 | 0 | 10g + oo1 + o1 + n1 | 28.28 | 0.277

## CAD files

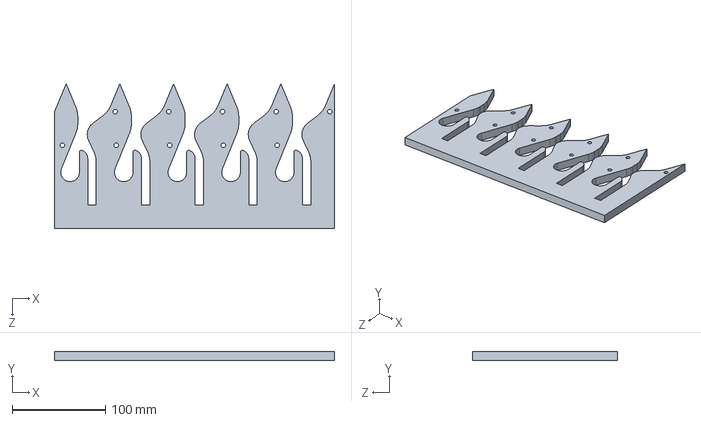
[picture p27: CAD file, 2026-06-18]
CAD_Models/SOLIDWORKS_Files/Guide_C.SLDPRT
300.0 x 10.0 x 155.0 mm

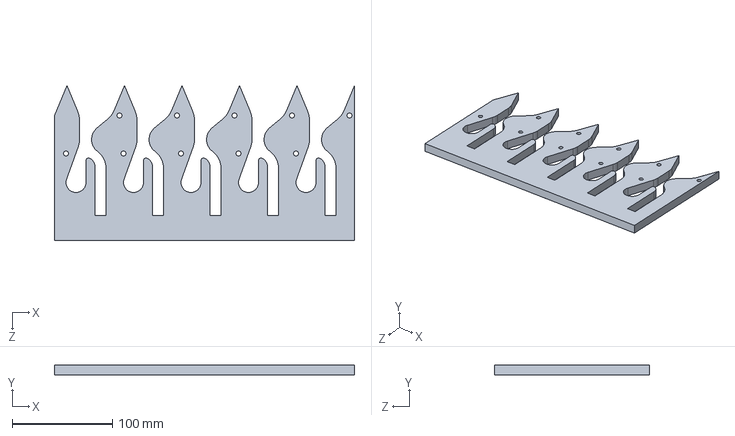
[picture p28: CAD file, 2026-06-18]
CAD_Models/SOLIDWORKS_Files/Guide_B.SLDPRT
300.0 x 10.0 x 155.0 mm

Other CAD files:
CAD_Models/SOLIDWORKS_Files/Guide_A.SLDPRT

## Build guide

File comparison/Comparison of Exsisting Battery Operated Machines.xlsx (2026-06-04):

Parameter | BOMA-SETH-300 | BOMA BMTH-300-1 | NAACHI ELEKTRA-330 | NAACHI ELEKTRA-330 PRO | NPLUS J30C |  | Farmer EH-35 | BOMA-SETH-300 | https://www.bomatools.com/electric-single-hand-mini-tea-harvester.html?utm_
Manufacturer | BOMA | BOMA | Naachi | Naachi | Zhejiang Nplus Intelligent Technology Co., Ltd. | PCL Solusions (PVT). Ltd | Farmer | BOMA BMTH-300-1 | https://www.bomatools.com/24V-10Ah-Long-Blade-Tea-Harvester-Professional-Tea-Picking-Machine-pd761663388.html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
Motor Type | Brushless | Brushless | Brushless | BLDC | Brushless | Brushless | Brushless Motor | NAACHI ELEKTRA-330 | https://naachi.world/product/elektra-330/?utm_source=chatgpt.com
Motor Power | 60W |  | 300 W | 500 W | 750 W |  | 300 W | NAACHI ELEKTRA-330 PRO | https://naachi.world/product/electra-330-pro/?utm
Motor Speed |  |  | 24,000 RPM | 13,000 RPM |  | 9000–10000 rpm | 5500 RPM | NPLUS J30C | https://www.zjnplus.com/tea-picking-machine/j30c-large-capacity-lithium-battery-tea.html?utm
Rated Voltage | 24V | 24V / 12V | 24 V | 21 V | 36 V | DC 24V / 12V optional |  | PCL Solusions (PVT). Ltd | https://www.pclsolutions.lk/agriculture-and-plantation/?utm
Blade Length | 300mm | 330 mm | 330 mm | 330 mm | 376 mm | 330mm | 300mm | Farmer EH-35 | https://www.zenithforgings.com/eh35.html?utm_
Blade Material |  |  | SKS51 Japanese Steel | SKS85 Japanese Steel | SK5 High Carbon Steel |  | Japanese Steel
Blade Speed |  |  |  | 1900–2400 CPM |  |  | 1800 RPM
Transmission |  |  |  | Dual Action Syncro Gearbox
Collection Tray | Large Tray | Large Tray | 4.6 L Tray | Tray | Tray | Tray | Tray
Machine Weight | 2.1 kg | 1.8 kg | 1.6 kg | 1.29 kg | 4.0 kg (with battery) | 1.6 kg | 1.12 Kg
Battery Type | Lead acid battery 24V DC 8AH | Lithium battery (24v,12ah or 10ah ) / lead acid battery | Lithium-ion | Lithium-ion | Lithium-ion | Lithium battery (24v) / lead acid battery | Lithium-lon Battery
Battery Capacity | 24V 12Ah | 24V 10Ah or 12Ah | 24V 12Ah | 21V 4Ah | 7.8Ah | 24V 10Ah | 24V 12Ah
Battery Energy |  |  | 350 Wh | 84 Wh
Battery Weight |  |  | 2.4 kg | 0.6 kg | Included in total weight |  | 0.6 Kg
Charging Time |  |  | 6–7 h | 3 h
Runtime | 3-5 h | 6–7 h | 1.5–2 days | 12+ h | 6 h | 7–8 h (24V 10Ah) | 10 - 12 Hours/day
Harvesting Capacity | >30 kg/h | >60 kg/h | 400–500 kg/day | 400–500 kg/day | ≈500 kg/day | >60 kg/h
Waterproof |  | Yes |  |  | Rating IP65 | Yes
Circuit Protection |  | Yes |  | Battery Management System |  | Yes
Reverse Polarity Protection |  | Yes
Cutting Mechanism | Reciprocating Cutter | Reciprocating Cutter | Reciprocating Cutter | Reciprocating Cutter | Reciprocating Cutter | Reciprocating Cutter | Reciprocating Cutter
Drive System |  | Electric Motor + Gear Reduction | BLDC + Gearbox | BLDC + Syncro Gearbox | BLDC Drive
Battery Location | Backpack Battery | Backpack Battery | Backpack Battery | Portable Battery Pack | Backpack Battery | Backpack Battery | Backpack Battery
Intended Operation | Single-Hand | Single-Hand | Single-Hand | Single-Hand | Single-Hand | Single-Hand | Single-Hand
Terrain Suitability |  | Tea Estates | Tea Estates | Steep Terrain | Commercial Tea Fields |  | Steep Terrain
BOMA-SETH-300 |  | BOMA BMTH-300-1 |  | NAACHI ELEKTRA-330 |  | NAACHI ELEKTRA-330 PRO |  | NPLUS J30C
 |  |  |  |  |  |  |  |  |  | PCL Solusions (PVT). Ltd

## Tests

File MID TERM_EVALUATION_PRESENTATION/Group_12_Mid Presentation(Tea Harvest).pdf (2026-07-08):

# Adaptive Stiffness-Based

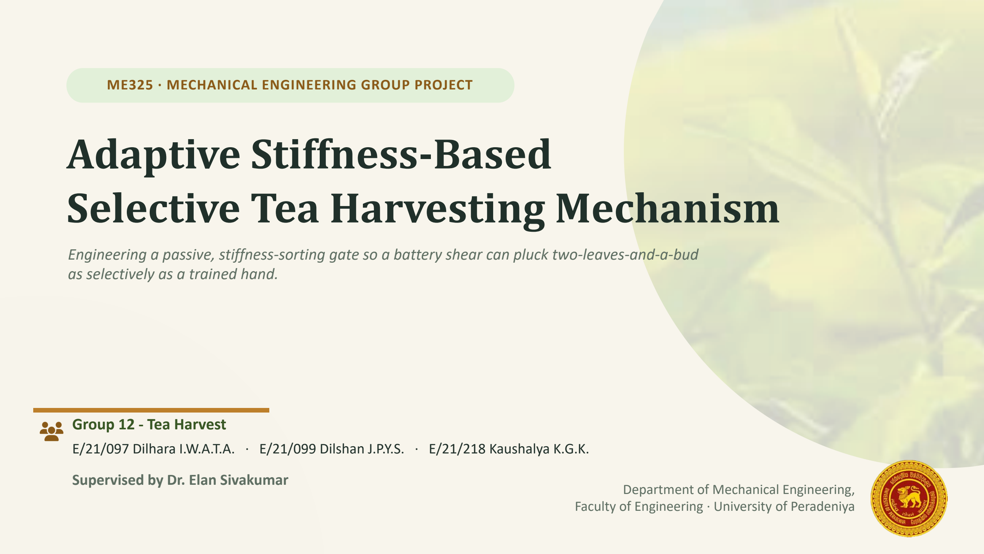
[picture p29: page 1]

ME325 · MECHANICAL ENGINEERING GROUP PROJECT

# Selective Tea Harvesting Mechanism

Engineering a passive, stiffness-sorting gate so a battery shear can pluck two-leaves-and-a-bud
as selectively as a trained hand.

Group 12 - Tea Harvest
E/21/097 Dilhara I.W.A.T.A. · E/21/099 Dilshan J.P.Y.S. · E/21/218 Kaushalya K.G.K.
Supervised by Dr. Elan Sivakumar | Department of Mechanical Engineering, Faculty of Engineering · University of Peradeniya

# What We Set Out to Build

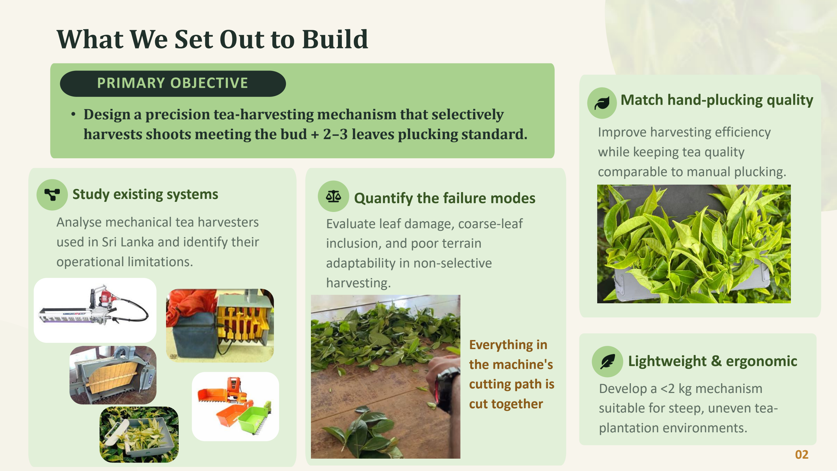
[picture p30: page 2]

PRIMARY OBJECTIVE

- Design a precision tea-harvesting mechanism that selectively harvests shoots meeting the bud + 2–3 leaves plucking standard.

Study existing systems

Analyse mechanical tea harvesters used in Sri Lanka and identify their operational limitations.

Quantify the failure modes

Evaluate leaf damage, coarse-leaf inclusion, and poor terrain adaptability in non-selective harvesting.

Lightweight & ergonomic

Develop a <2 kg mechanism
suitable for steep, uneven teaplantation environments.

Match hand-plucking quality

Improve harvesting efficiency
while keeping tea quality
comparable to manual plucking.

02

Everything in
the machine's
cutting path is
cut together

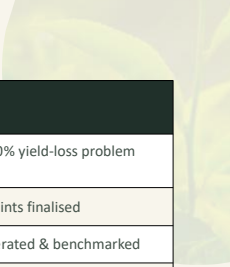
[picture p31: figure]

03

Milestone | Due | Completion Status | Remarks
Literature Review & Problem Identification | Week 2 | 100% | TRI field study complete; 35–40% yield-loss problem confirmed
Requirement Analysis | Week 3 | 100% | Design requirements & constraints finalised
Concept Generation | Week 4 | 100% | Three candidate concepts generated & benchmarked
Concept Evaluation & Selection | Week 5 | 100% | Stiffness-based sorting gate selected
Material Selection / Engineering Calculations | Week 6, 7 | 70% | Bending-force field data + statistical threshold derived
3D CAD Modelling / Simulation & Validation | Week 8, 9, 10 | 70% | Gate geometry modelled; laser-cut prototype field-tested; FEA validation ongoing
Comparative Evaluation | Week 11 | 20% | Host machine acquired; integration benchmarking starting
Final Design Recommendation | Week 12 | 0% | Upcoming

# Milestones & Completion Status

04

# Problem Definition

Across three months of field work and engineering analysis, we moved from a confirmed industry problem to a statistically-derived, mechanically-validated sorting threshold.

THE PROBLEM
- TRI Ratnapura Field Insight: Observation of existing machines confirmed they lack any selectivity—cutting buds, stems, and immature shoots together.
- Critical Yield Loss: Non-selective cutting accidentally removes "Arimbu" (immature shoots), destroying the crop intended for the next 7-day plucking round.
- Permanent Plant Damage (Non-selective cutting leads to long-term decline in bush health).
- Industrial Damage: High inclusion of coarse wood stems disrupts automated factory sifting and lowers the final value grade of the tea.
- Economic Crisis: Manual harvesting is highly selective but increasingly unsustainable due to labor shortages and high costs (Rs. 375 per kg)

35–40%

estimated yield loss from non-selective mechanical harvesting

# Existing Selective Systems and Limitations

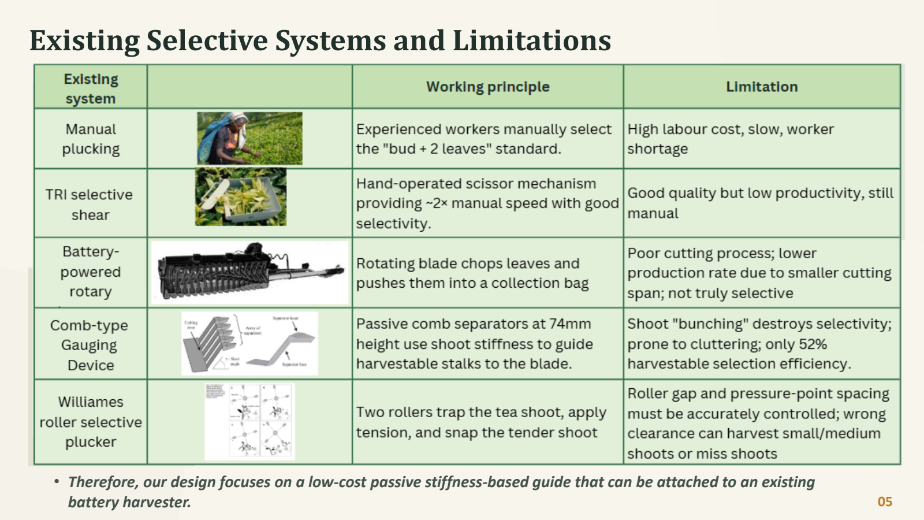
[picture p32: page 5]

05

- Therefore, our design focuses on a low-cost passive stiffness-based guide that can be attached to an existing battery harvester.

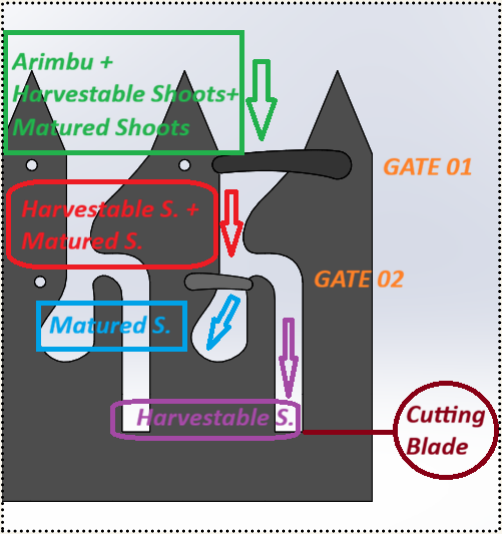
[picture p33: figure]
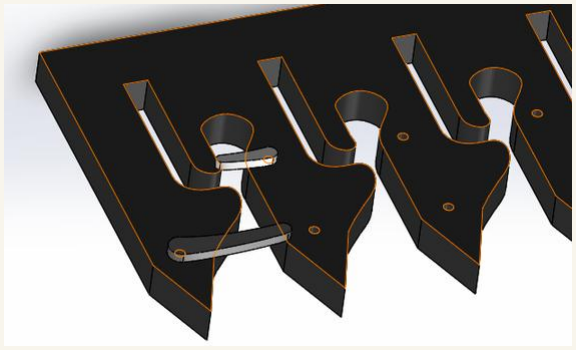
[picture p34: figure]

06

# Concept Selection

- Speed vs. Selectivity: Reviewed existing selective and non-selective tea harvesting systems to identify the main gap: high speed but poor selectivity.
- Concept Selection: Evaluated three options (Sensor-based, Optical, and Stiffness-based)
- Why Stiffness-Based Gate? Selected because it is purely mechanical, requires no expensive sensors.
- Dual-Filter Mechanism:
⚬ Gate 1: Flexible Arimbu shoots are filtered out because they lack the force to trigger the gate.
⚬ Gate 2: Mature shoots apply enough force to open the gate and are diverted into the slot, while harvestable shoots do not trigger the gate and continue toward the blade for cutting.

BENCHMARKING & DECISION

# Data Colection

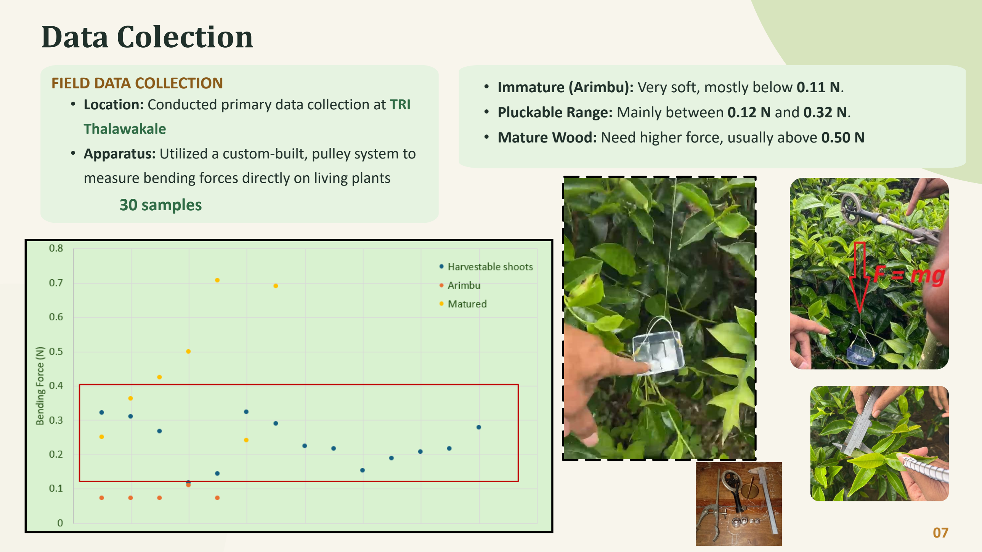
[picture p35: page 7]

07

- Location: Conducted primary data collection at TRI Thalawakale
- Apparatus: Utilized a custom-built, pulley system to measure bending forces directly on living plants

FIELD DATA COLLECTION

### 30 samples

- Immature (Arimbu): Very soft, mostly below 0.11 N.
- Pluckable Range: Mainly between 0.12 N and 0.32 N.
- Mature Wood: Need higher force, usually above 0.50 N

# Mechanism Design, Prototyping & Validation

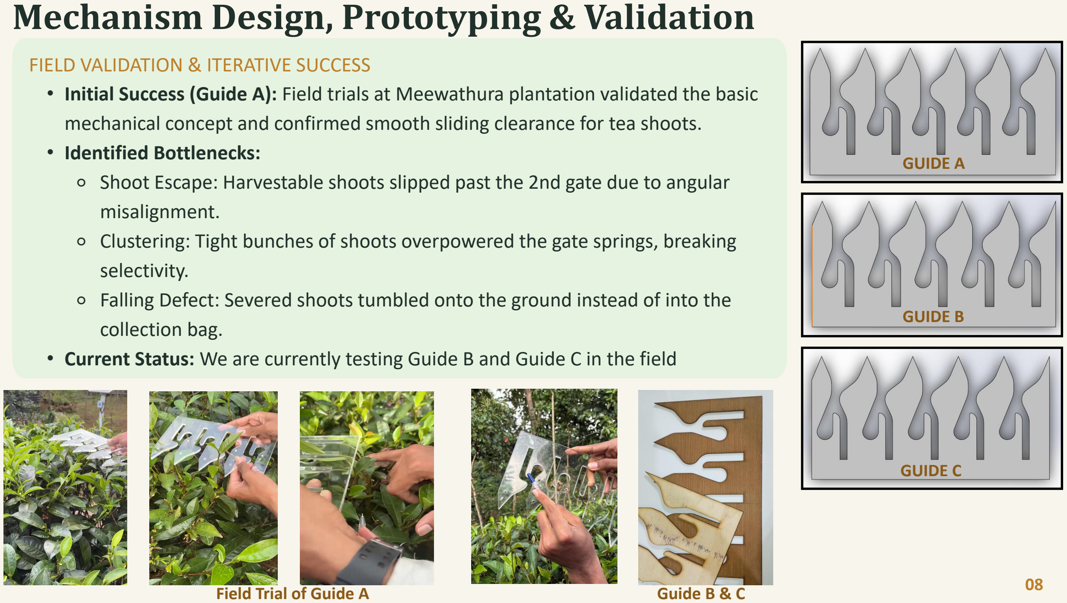
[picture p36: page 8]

08

GUIDE A

FIELD VALIDATION & ITERATIVE SUCCESS
- Initial Success (Guide A): Field trials at Meewathura plantation validated the basic mechanical concept and confirmed smooth sliding clearance for tea shoots.
- Identified Bottlenecks:
⚬ Shoot Escape: Harvestable shoots slipped past the 2nd gate due to angular misalignment.
⚬ Clustering: Tight bunches of shoots overpowered the gate springs, breaking selectivity.
⚬ Falling Defect: Severed shoots tumbled onto the ground instead of into the collection bag.
- Current Status: We are currently testing Guide B and Guide C in the field

GUIDE B

GUIDE C

Field Trial of Guide A | Guide B & C

09

# Engineering Calculations & Mathematical Basis

Establishing the scientific foundation for the stiffness-sorting mechanism through statistical analysis and mechanical modeling

Selection Logic: Optimal Threshold Force (Fopt)

The mechanism is calibrated to the intersection of pluckable (P) and mature (M) force distributions to minimize sorting errors.
- F / μ / σ: Bending force, its Mean, and Standard Deviation.
- Key Result: Fopt=0.34 N (The mechanical trigger point).

Mechanical Gate Design

Torsion springs are preloaded to ensure gates only trigger at the correct maturity level.
- T / θ / d: Spring torque, Gate angle, and Contact distance from pivot.
- Fmax: Marginal maximum force (μ+3σ) to ensure 99.7% filtering accuracy.
- Requirements: T1 ≥ 0.0027 Nm (Arimbu Filter) | T2 ≥ 0.0014 Nm (Stiffness Filter).

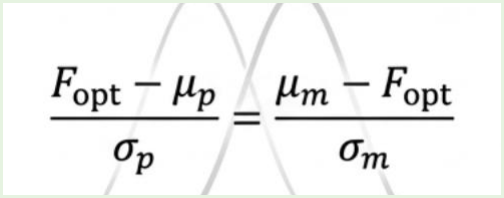
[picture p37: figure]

# Engineering Calculations & Mathematical Basis (Cont.)

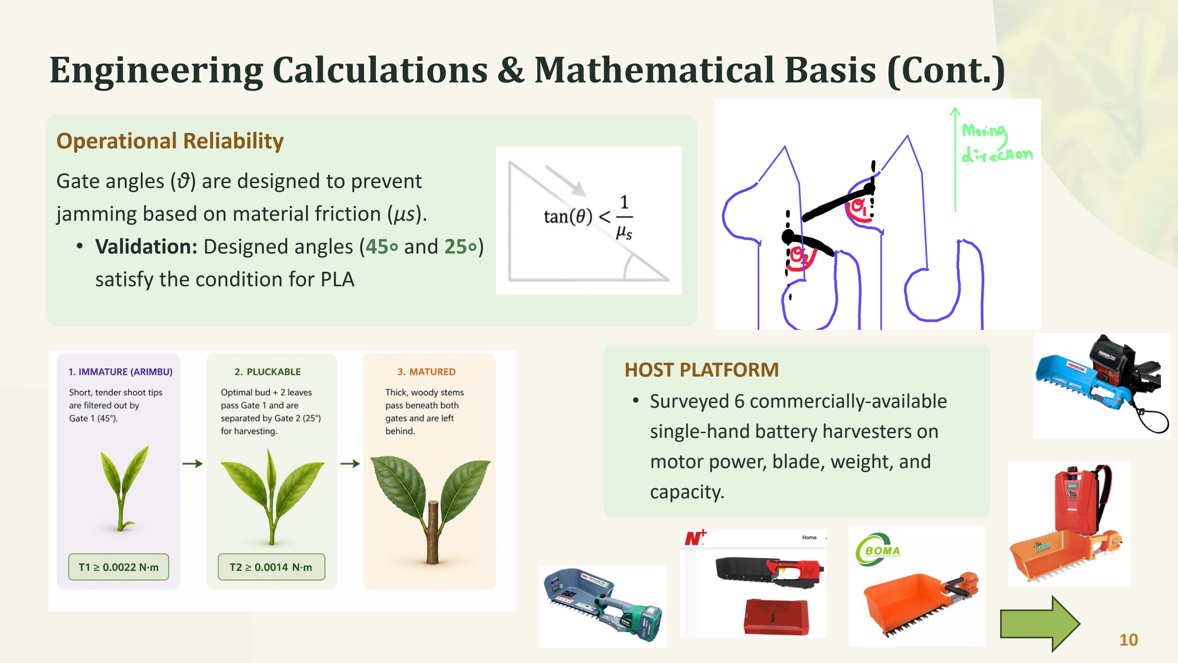
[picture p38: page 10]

10

Operational Reliability

Gate angles (θ) are designed to prevent jamming based on material friction (μs).
- Validation: Designed angles (45∘ and 25∘) satisfy the condition for PLA

HOST PLATFORM
- Surveyed 6 commercially-available single-hand battery harvesters on motor power, blade, weight, and capacity.

# Theoretical Yield & System Efficiency


- Total Theoretical Yield: ❑ 80.5% Calculated prediction shows that over 80% of ideal pluckable shoots are successfully harvested
- System Rejection Rates:
❑ Gate 1 Rejection (5.8%): Shoots too flexible (< 0.108 N) to trigger the filter
❑ Gate 2 Rejection (13.7%): Shoots too stiff (> 0.220 N), filtered to ensure zero mature wood inclusion
- Statistical Basis:
❑ Derived from TRI
Thalawakale field data:
Mean (μ) = 0.174 N
Std Dev (σ) = 0.042 N

# Integration Plan & Next Steps

- Status Update: We have purchased a battery-operated machine.


- Next Phase: We plan to assemble the selection mechanism (Guide) to it and conduct full-scale performance checks at the Meewathura tea field

WHERE WE STAND
Week 9 of 12 — concept selected, field data collected, and engineering calculations complete. The 3D model is being built and validated; a laser-cut prototype is already field-tested, and integration onto the acquired host machine is underway.

Mount the gate stack; Fix the two-gate comb-guide assembly ahead of the acquired shear's reciprocating blade.; Calibrate spring preload; Set torsion-spring preload to T₁≥0.0022 N·m and T₂≥0.0014 N·m using the derived thresholds.; 03 Run controlled cutting trials; Test on live bushes . (Testing on live bushes at the Meewathura tea field); Benchmark vs. manual plucking Measure selectivity rate, leaf- damage incidence, and throughput against the TRI hand-shear baseline.

Q&A

## Thank you — questions & discussion welcome

E/21/097 Dilhara I.W.A.T.A. · E/21/099 Dilshan J.P.Y.S. · E/21/218 Kaushalya K.G.K.

Supervised by Dr. Elan Sivakumar

12

Project Repository
github.com/ (https://github.com/TADilhara/3YP-ME325-)TADilhara (https://github.com/TADilhara/3YP-ME325-)/Selective (https://github.com/TADilhara/3YP-ME325-)- (https://github.com/TADilhara/3YP-ME325-)Tea (https://github.com/TADilhara/3YP-ME325-)- (https://github.com/TADilhara/3YP-ME325-)Harvester (https://github.com/TADilhara/3YP-ME325-)- (https://github.com/TADilhara/3YP-ME325-)Stiffness (https://github.com/TADilhara/3YP-ME325-)- (https://github.com/TADilhara/3YP-ME325-)Gate (https://github.com/TADilhara/3YP-ME325-) Scan the QR code

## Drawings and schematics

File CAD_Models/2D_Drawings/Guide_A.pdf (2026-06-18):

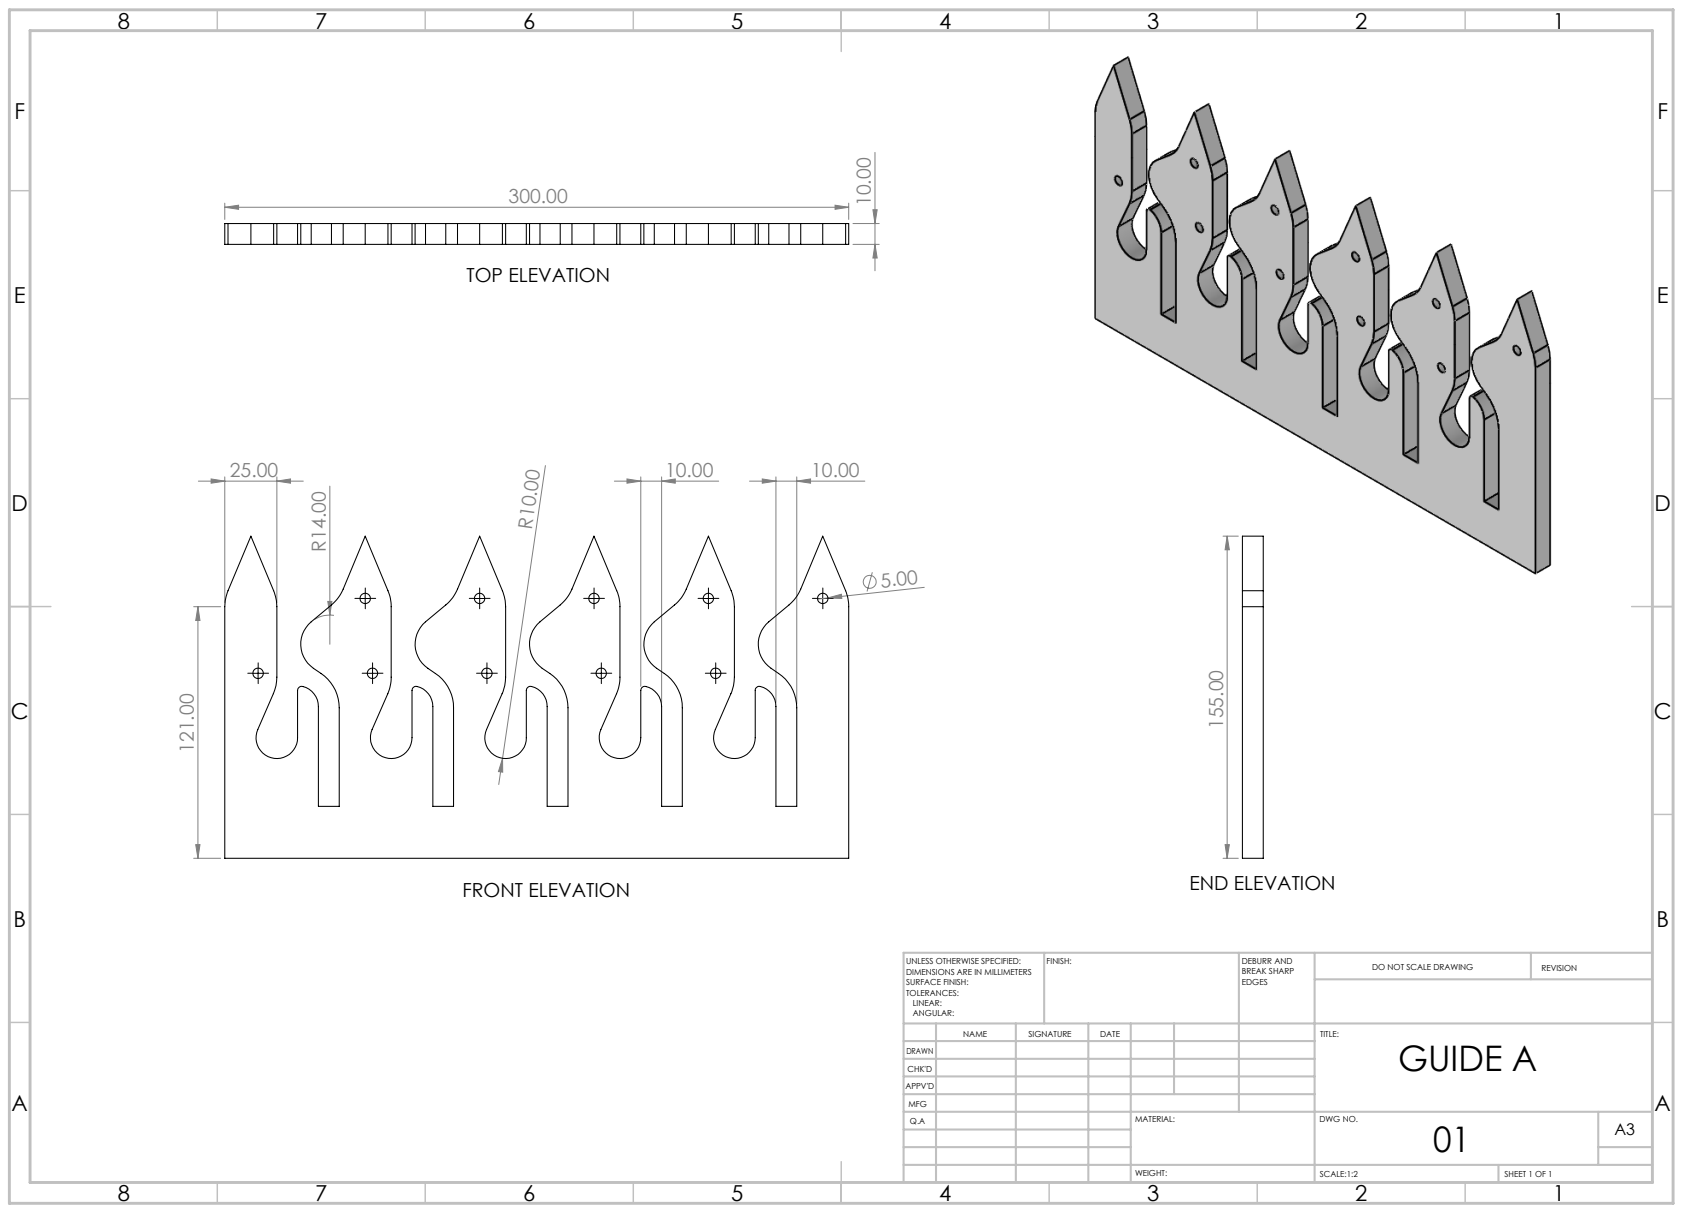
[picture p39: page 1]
FRONT ELEVATION; TOP ELEVATION; END ELEVATION; FINISH:; DEBURR AND; BREAK SHARP; DO NOT SCALE DRAWING; REVISION; SCALE:1:2; SHEET 1 OF 1

UNLESS OTHERWISE SPECIFIED:
DIMENSIONS ARE IN MILLIMETERS
SURFACE FINISH:
TOLERANCES:
LINEAR:
ANGULAR:

NAME | SIGNATURE | DATE | | | | TITLE: GUIDE A

DRAWN
CHK'D
APPV'D
MFG
Q.A | | | | MATERIAL: | DWG NO. 01 | A3
